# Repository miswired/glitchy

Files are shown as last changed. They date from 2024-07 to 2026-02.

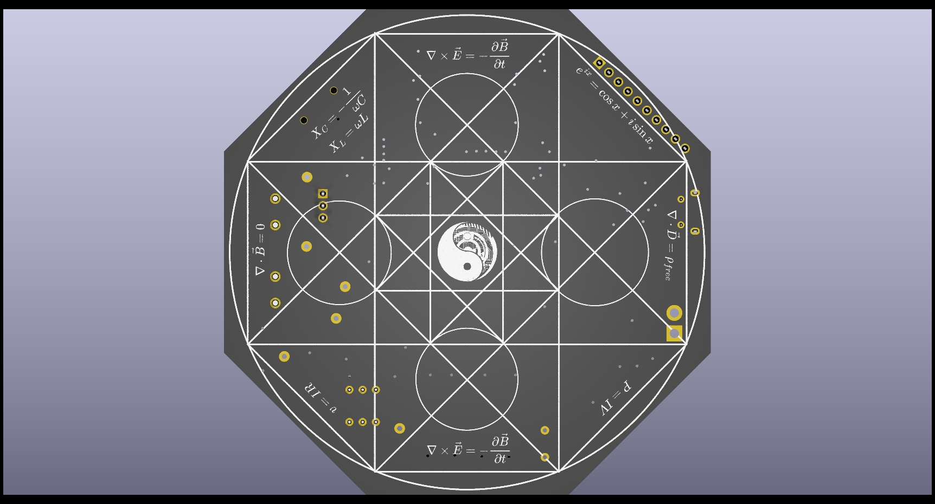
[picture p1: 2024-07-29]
PCB/Docs/Board2.png

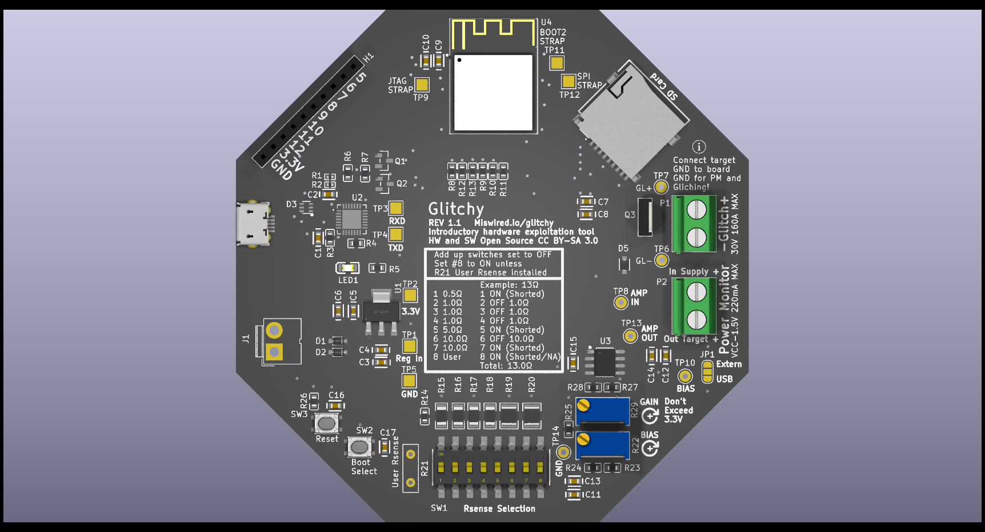
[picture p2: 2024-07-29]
PCB/Docs/Board1.png

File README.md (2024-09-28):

# CircuitBreakerGadget

## Project Overview
Designed as an introduction into hardware hacking, the Glitchy can do power glitching to alter program execution and power analysis for extracting secrets from chips. 
See the [wiki](https://github.com/miswired/glitchy/wiki) for setup instructions and guides to performing the labs with the kit.

## Install
This project is hosted in two repos. The board firmware and PCB is hosted here. Please see the following instructions for setting up the build enviroment and programming. [Arduino-Setup](https://github.com/miswired/glitchy/wiki/Guide-%E2%80%90-Arduino-Setup)   

**The web gui has be substatually upgradded by Philip Kopyscinski!**  
See the following repo for the files you need to put on the SD card.  
https://github.com/pkopysci/miswired-glitchy-vue-app

## Comming Features
* Scripting power analysis attack
* Configure wifi from a config file on sd card isntead of having to reprogram

## Release Notes
### 2.0.0
#### New Features
* Completely new web GUI!!!
* Adjustability of glitching parameters from web interface

### 1.1.0
#### New Features
* None

#### Bug Fixes
* Fixed loading bug for the web interface

#### Backlog

* Add configuration of the glitching settings to the web interface instead of needing to reflash the chip
* Add wifi configuration to a config.ini file on the SD card instead of needing to reflash the chip

## Project Setup
Install Arduino IDE V1. Please see the following wiki for a setup guide. [Arduino-Setup](https://github.com/miswired/glitchy/wiki/Guide-%E2%80%90-Arduino-Setup)  

## Colaborators
**Miswired**  
https://github.com/miswired  
PCB Board and firmware  
  
**Philip J Kopyscinski**  
https://github.com/pkopysci  
Web GUI

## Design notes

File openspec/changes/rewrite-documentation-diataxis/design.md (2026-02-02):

# Design: Documentation Rewrite

## Context

Glitchy is an open-source hardware hacking educational kit targeting security researchers, embedded engineers, and students. Documentation must serve:
- **Beginners**: No prior hardware/security knowledge assumed
- **Experts**: Quick access to technical details without wading through basics
- **Instructors**: Materials for live classroom teaching
- **Contributors**: Clear understanding of project architecture

The Diataxis framework (https://diataxis.fr/) provides a systematic approach by categorizing documentation into four types based on user needs.

## Goals / Non-Goals

### Goals
- Complete restructure of wiki following Diataxis principles
- Fill all documentation gaps (currently 3 major TODOs)
- Create reusable classroom lesson plans
- Design dark-mode compatible SVG diagrams
- Establish consistent formatting standards

### Non-Goals
- Video tutorials (future consideration)
- Translations/internationalization
- Interactive web-based labs
- Changes to firmware or web GUI code

## Decisions

### Decision: Diataxis Four-Quadrant Structure

**Rationale**: Diataxis is proven at Gatsby, Cloudflare, Django. It provides clear separation of concerns:

| Quadrant | User Need | Content Type |
|---|---|---|
| Tutorial | Learning | Lessons with hands-on exercises |
| How-To | Doing | Task-focused guides |
| Reference | Looking up | Technical specifications |
| Explanation | Understanding | Conceptual background |

**Alternatives Considered**:
- Simple linear progression → Doesn't serve expert users well
- Topic-based organization → Mixes learning with reference
- Persona-based (beginner/advanced) → Creates duplication

### Decision: SVG Diagrams with CSS Variables

**Rationale**: SVGs scale perfectly, support theming, and are accessible.

```svg
<svg>
  <style>
    :root { --fg: currentColor; --bg: transparent; }
    @media (prefers-color-scheme: dark) {
      :root { --fg: #E0E0E0; --bg: #121212; }
    }
  </style>
</svg>
```

**Alternatives Considered**:
- PNG with light/dark versions → Doubles maintenance burden
- External Figma embeds → Requires account, breaks offline access
- ASCII art → Insufficient for circuit diagrams

### Decision: Wiki-Embedded Assets

**Rationale**: GitHub wiki repos support assets. Keeping diagrams with docs ensures:
- Single source of truth
- Version control for diagrams
- No external dependencies
- Works offline when cloned

**Directory Structure**:
```
glitchy.wiki/
├── assets/
│   └── diagrams/
│       ├── system-architecture.svg
│       ├── pinout-esp32s3.svg
│       ├── glitch-timing-waveform.svg
│       ├── power-analysis-flow.svg
│       ├── crowbar-circuit.svg
│       └── web-interface-map.svg
```

### Decision: Dual-Format Classroom Materials

**Rationale**: Users want both self-paced study and instructor-led classes.

Each lesson includes:
- **Instructor Guide**: Teaching notes, timing, discussion questions
- **Student Materials**: Exercises, expected outcomes
- **Slide Diagrams**: SVGs optimized for projection

**Lesson Structure**:
```markdown
# Lesson N: Topic

## Overview (Instructor)
- Duration: 45 minutes
- Prerequisites: Lesson N-1
- Materials needed: [list]

## Learning Objectives
Students will be able to:
- [ ] Objective 1
- [ ] Objective 2

## Lesson Content
### Section 1 (10 min)
[Content with instructor notes in blockquotes]

### Hands-On Exercise (20 min)
[Step-by-step with checkpoints]

### Discussion (10 min)
[Questions and wrap-up]

## Self-Study Notes
[Modifications for independent learners]
```

## Risks / Trade-offs

| Risk | Mitigation |
|---|---|
| Large scope causes stalls | Phase implementation: research first, then core docs, then diagrams, then classroom |
| Diagrams become outdated | Store editable sources, document design system |
| Diataxis feels bureaucratic | Keep it pragmatic - serve users, not the framework |
| GitHub wiki limitations | Test rendering early, have fallback plans |
| Inaccurate technical content | Research-first approach with authoritative sources; dual-source verification |
| Unverifiable claims | Every technical claim must cite authoritative source; no unsourced assertions |
| AI hallucination in content | All generated content verified against primary sources before publication |

## Migration Plan

### Phase 0: Research & Verification (NEW - Critical)
1. Compile authoritative sources for all technical topics
2. Research glitching theory from academic papers
3. Research power analysis from foundational DPA/SPA literature
4. Verify circuit design against datasheets and application notes
5. Create Reference-Sources.md documenting all authoritative sources

**Authoritative Sources to Consult:**
- **Hardware Security**: CHES conference papers, Kocher et al. DPA papers, ChipWhisperer research
- **Electronics**: Espressif ESP32-S3 TRM, component datasheets, manufacturer app notes
- **Books**: "Power Analysis Attacks" (Mangard/Oswald/Popp), "The Hardware Hacker" (Huang)
- **Standards**: NIST guidelines on side-channel resistance

### Phase 1: Core Structure (Foundation)
1. Create new directory structure in wiki
2. Migrate existing content to appropriate quadrants
3. Add clear deprecation notices to old locations
4. Create Home.md navigation hub

### Phase 2: Fill Critical Gaps
1. Write PlatformIO setup guide
2. Write power analysis theory explanation
3. Write circuit explanation
4. Create troubleshooting guide

### Phase 3: Visual Assets
1. Design diagram style guide (colors, fonts, spacing)
2. Create system architecture diagram
3. Create pinout diagram
4. Create timing/waveform diagrams
5. Create power analysis flow diagram

### Phase 4: Reference Documentation
1. Document pin assignments
2. Document WebSocket API protocol
3. Document glitch parameters
4. Create Bill of Materials

### Phase 5: Classroom Materials
1. Create instructor overview guide
2. Create Lesson 1: Introduction to Hardware Security
3. Create Lesson 2: Setting Up Your Lab
4. Create Lesson 3: Power Glitching Hands-On
5. Create Lesson 4: Power Analysis Hands-On

### Rollback
- Keep original files until new structure is validated
- Use git branches for major changes
- Maintain redirects from old URLs

## Open Questions

1. **Lesson duration**: Should lessons target 45-min, 60-min, or 90-min class periods?
2. **Prerequisite knowledge**: Should we include embedded systems basics or link externally?
3. **Diagram tool**: Should we standardize on a specific SVG editor (Inkscape, Figma, etc.)?
4. **Assessment**: Should classroom lessons include quizzes or knowledge checks?

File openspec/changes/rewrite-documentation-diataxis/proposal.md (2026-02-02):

# Change: Rewrite Documentation Using Diataxis Framework

## Why

The current wiki documentation has significant gaps that hinder both new users and contributors:
- 3 critical sections marked TODO (PlatformIO setup, Power Analysis Theory, Circuit Explanation)
- Deprecated Arduino IDE guide still prominently displayed
- No visual diagrams or architecture documentation
- Mixed documentation types causing confusion (tutorials vs how-to guides)
- No structured classroom/lesson materials for educational use
- Inconsistent formatting and incomplete troubleshooting

The Diataxis framework provides a proven structure that separates documentation by user need: learning (tutorials), doing (how-to), looking up (reference), and understanding (explanation).

## What Changes

### New Documentation Structure
- **Reorganize all content** into four Diataxis quadrants plus classroom section
- **Create missing documentation**: PlatformIO setup, power analysis theory, circuit explanation, architecture overview, troubleshooting guide
- **Add reference section**: Pinout, Web API protocol, parameters, BOM, schematic reference
- **Add classroom section**: Self-paced modules and instructor-led lesson plans

### Visual Improvements
- **Create SVG diagrams** for: system architecture, pinout, glitch timing, power analysis flow, waveform annotations
- **Design for dark mode**: Use `currentColor`, CSS variables, WCAG-compliant contrast
- **Embed directly in wiki**: Store SVGs in wiki repo for inline rendering

### Deprecation Handling
- **Archive Arduino-Setup.md** with clear migration notice
- **Remove TODO placeholders** by filling in actual content

### Quality Improvements
- **Consistent formatting** across all documents
- **Add estimated times** to tutorials and labs
- **Add prerequisites** to each document
- **Add troubleshooting sections** where appropriate

## Impact

- **Affected specs**: documentation (new capability)
- **Affected repositories**: glitchy.wiki (primary), glitchy/openspec (specs)
- **User impact**: Significantly improved onboarding and learning experience
- **Contributor impact**: Clear structure makes contributions easier
- **Breaking changes**: None - documentation only

## Success Criteria

1. All TODO items resolved with actual content
2. Every document categorized into exactly one Diataxis quadrant
3. Minimum 6 SVG diagrams created with dark mode support
4. Classroom section with at least 4 lesson plans
5. All documentation passes Diataxis validation (no mixed types)
6. New user can go from zero to first successful glitch using only documentation

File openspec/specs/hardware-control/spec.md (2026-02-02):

# Hardware Control Capability

## Purpose
The hardware control module manages low-level hardware interfaces including GPIO pin configuration, SPI bus setup, SD card access, and timer interrupts. It provides the foundation for glitching and power analysis operations.

## Requirements

### Requirement: Pin Configuration
The system SHALL configure GPIO pins according to their designated functions for glitching, power analysis, and communication.

#### Scenario: Glitching pin setup
- **WHEN** the system initializes
- **THEN** POWER_GLITCH_PIN (15) is configured as output for FET control
- **AND** ENTER_KEY_PIN (11) is configured as output for target triggering
- **AND** GLITCH_SUCCESS_PIN (12) is configured as input for success detection

#### Scenario: Analog pin setup
- **WHEN** the system initializes
- **THEN** AMP_IN_PIN (4) is configured for ADC input
- **AND** BIAS_IN_PIN (2) is configured for bias voltage input

#### Scenario: Key input pin setup
- **WHEN** the system initializes
- **THEN** KEY_1_PIN (5), KEY_2_PIN (6), KEY_3_PIN (7) are configured as inputs for differential analysis

### Requirement: SPI Bus Configuration
The system SHALL configure dual SPI buses: FSPI for FET control and HSPI for SD card access.

#### Scenario: FSPI initialization for glitching
- **WHEN** glitch module initializes
- **THEN** FSPI bus is configured with pins 13-16 for high-speed FET control

#### Scenario: HSPI initialization for SD card
- **WHEN** SD card module initializes
- **THEN** HSPI bus is configured with pins 39-41, 47 for SD card communication

### Requirement: SD Card Access
The system SHALL mount and access an SD card for storing the web GUI files and configuration.

#### Scenario: SD card mount on boot
- **WHEN** the system starts
- **THEN** the SD card is mounted and verified accessible

#### Scenario: SD card error handling
- **WHEN** SD card is not present or fails to mount
- **THEN** the system reports the error and continues with limited functionality

### Requirement: Timer Interrupts
The system SHALL use hardware timer interrupts for periodic task scheduling including ADC streaming and status updates.

#### Scenario: Timer initialization
- **WHEN** the system starts
- **THEN** a hardware timer is configured for periodic interrupt callbacks

#### Scenario: Periodic task execution
- **WHEN** timer interrupt fires
- **THEN** scheduled tasks (ADC reads, status updates) are executed

### Requirement: System Initialization Sequence
The system SHALL follow a defined initialization sequence to ensure all hardware is properly configured before operation.

#### Scenario: Boot sequence
- **WHEN** the system powers on
- **THEN** initialization proceeds in order: WiFi, SD card, web server, WebSocket, glitch module, ADC
- **AND** each stage reports success or failure before proceeding

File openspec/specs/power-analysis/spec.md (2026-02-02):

# Power Analysis Capability

## Purpose
The power analysis module provides real-time monitoring of target device power consumption using fast ADC sampling. This enables side-channel attacks where cryptographic secrets can be extracted by analyzing power consumption patterns during cryptographic operations.

## Requirements

### Requirement: Fast ADC Initialization
The system SHALL initialize a fast ADC driver on the AMP_IN_PIN with 12-bit resolution and 11dB attenuation for power measurement.

#### Scenario: ADC setup on boot
- **WHEN** the system starts up
- **THEN** the fast ADC is configured on pin 4 (AMP_IN_PIN) with calibration applied

#### Scenario: ADC calibration
- **WHEN** ADC is initialized
- **THEN** hardware calibration coefficients are applied for accurate voltage readings

### Requirement: Real-Time ADC Streaming
The system SHALL stream ADC samples to the web interface via WebSocket for real-time power consumption visualization.

#### Scenario: Enable streaming mode
- **WHEN** user enables amp bias streaming via web interface
- **THEN** the system continuously samples ADC and sends values over WebSocket

#### Scenario: Streaming rate control
- **WHEN** streaming is active
- **THEN** samples are sent at a configurable rate (default 100ms intervals)

### Requirement: Sample Buffering
The system SHALL maintain sample buffers for differential power analysis across multiple key operations.

#### Scenario: Buffer allocation
- **WHEN** performing differential analysis
- **THEN** three 1000-sample buffers are available for comparing power traces from different key inputs

#### Scenario: Buffer capture on key press
- **WHEN** a key input pin (KEY_1, KEY_2, or KEY_3) is activated
- **THEN** the corresponding buffer captures 1000 ADC samples during the operation

### Requirement: Differential Power Analysis
The system SHALL support differential power analysis by comparing power traces from operations with different input keys.

#### Scenario: Run key difference analysis
- **WHEN** user initiates key difference analysis
- **THEN** the system compares buffered traces to identify power consumption differences correlated with key bits

### Requirement: Voltage Conversion
The system SHALL convert raw ADC values to calibrated voltage readings using DAC-to-voltage conversion constants.

#### Scenario: ADC to voltage conversion
- **WHEN** displaying or transmitting ADC readings
- **THEN** raw values are converted to millivolts using calibration polynomial

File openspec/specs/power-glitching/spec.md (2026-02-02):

# Power Glitching Capability

## Purpose
The power glitching module provides controlled voltage glitch attacks against target devices. It uses an SPI-driven FET to create precise nanosecond-scale power disruptions that can cause instruction skips or data corruption in target microcontrollers.

## Requirements

### Requirement: Glitch Parameter Configuration
The system SHALL allow configuration of glitch timing parameters including shortest delay, longest delay, step size, pause time between attempts, and number of attempts per step.

#### Scenario: Configure glitch parameters via web interface
- **WHEN** user submits new glitch parameters through the web UI
- **THEN** the system updates the internal glitch_param_t structure with the new values

#### Scenario: Default parameter initialization
- **WHEN** the system starts up
- **THEN** glitch parameters are initialized to safe defaults (200ns shortest, 1500ns longest, 10ns step, 3 attempts)

### Requirement: SPI-Driven Glitch Execution
The system SHALL use the FSPI bus to drive the power glitch FET with nanosecond-level timing precision.

#### Scenario: Execute single glitch pulse
- **WHEN** a glitch is triggered
- **THEN** the system sends an SPI transaction to create a precise voltage dip on the target power rail

#### Scenario: Glitch width control
- **WHEN** executing a glitch with a specified width
- **THEN** the FET remains active for the duration specified (within SPI timing constraints)

### Requirement: Automated Timing Sweep
The system SHALL automatically sweep through timing parameters to find vulnerable glitch windows.

#### Scenario: Parameter sweep execution
- **WHEN** user activates glitching via web interface
- **THEN** the system iterates from shortest_delay_ns to longest_delay_ns in step_size increments, executing num_of_attempts glitches at each timing

#### Scenario: Success detection during sweep
- **WHEN** the GLITCH_SUCCESS_PIN goes high during a sweep
- **THEN** the system records the successful timing parameters and reports via WebSocket

### Requirement: Target Trigger Synchronization
The system SHALL synchronize glitch timing with target device operations using the ENTER_KEY_PIN.

#### Scenario: Trigger target before glitch
- **WHEN** executing a glitch sequence
- **THEN** the system pulses ENTER_KEY_PIN to initiate the target operation before applying the glitch

### Requirement: Glitch Status Reporting
The system SHALL report glitch progress and results via WebSocket to the web interface.

#### Scenario: Progress updates during sweep
- **WHEN** a glitch sweep is in progress
- **THEN** the system sends periodic status updates including current timing and attempt count

#### Scenario: Success notification
- **WHEN** a glitch successfully bypasses target security
- **THEN** the system sends a success message with the effective timing parameters

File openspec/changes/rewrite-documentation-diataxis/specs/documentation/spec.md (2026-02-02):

## ADDED Requirements

### Requirement: Diataxis Documentation Structure
The documentation SHALL be organized into four distinct categories following the Diataxis framework: Tutorials (learning-oriented), How-To Guides (task-oriented), Reference (information-oriented), and Explanation (understanding-oriented).

#### Scenario: User seeks to learn a new skill
- **WHEN** a user wants to learn how to use Glitchy for the first time
- **THEN** they find tutorial documentation that guides them through hands-on exercises with clear learning objectives

#### Scenario: User needs to accomplish a specific task
- **WHEN** a user needs to configure WiFi or flash firmware
- **THEN** they find how-to guides focused on completing that specific task without extraneous explanation

#### Scenario: User needs to look up technical details
- **WHEN** a user needs pin assignments, API formats, or parameter specifications
- **THEN** they find reference documentation with authoritative, consistent technical information

#### Scenario: User wants to understand concepts
- **WHEN** a user wants to understand why glitching works or how the circuit is designed
- **THEN** they find explanation documentation that provides context, theory, and background

### Requirement: Classroom Lesson Materials
The documentation SHALL include structured lesson plans suitable for both self-paced learning and instructor-led classroom use.

#### Scenario: Instructor prepares a class
- **WHEN** an instructor wants to teach a hardware security class using Glitchy
- **THEN** they find lesson plans with timing guides, learning objectives, discussion questions, and hands-on exercises

#### Scenario: Student studies independently
- **WHEN** a student works through lessons without an instructor
- **THEN** the lesson materials include self-study notes and self-assessment checkpoints

### Requirement: Dark-Mode Compatible Diagrams
The documentation SHALL include SVG diagrams that render correctly in both light and dark display modes while meeting WCAG accessibility guidelines.

#### Scenario: User views diagram in dark mode
- **WHEN** a user with dark mode enabled views a diagram
- **THEN** the diagram automatically adapts colors for readability with minimum 4.5:1 contrast ratio for text

#### Scenario: Screen reader accesses diagram
- **WHEN** a screen reader encounters an SVG diagram
- **THEN** the diagram provides accessible title and description elements

### Requirement: Complete Reference Documentation
The documentation SHALL include reference materials for all hardware interfaces, software APIs, and configuration parameters.

#### Scenario: Developer looks up pin assignment
- **WHEN** a developer needs to know which GPIO controls the FET
- **THEN** they find a pinout reference with complete pin assignments and electrical specifications

#### Scenario: Developer integrates with web interface
- **WHEN** a developer wants to communicate with Glitchy programmatically
- **THEN** they find WebSocket API documentation with message formats and command reference

### Requirement: Troubleshooting Guide
The documentation SHALL include a troubleshooting guide organized by symptom to help users diagnose and resolve common issues.

#### Scenario: User encounters WiFi connection failure
- **WHEN** a user cannot connect to the Glitchy web interface
- **THEN** they find troubleshooting steps organized under WiFi/connection symptoms

#### Scenario: User's glitch attacks consistently fail
- **WHEN** a user cannot achieve successful glitches after multiple attempts
- **THEN** they find troubleshooting guidance for glitching failures with diagnostic steps

### Requirement: Technical Glossary
The documentation SHALL include a glossary of technical terms covering hardware security, embedded systems, and electronics terminology.

#### Scenario: User encounters unfamiliar term
- **WHEN** a user reads documentation containing technical jargon
- **THEN** they can look up the term in the glossary for a clear definition

### Requirement: Contribution Guidelines
The documentation SHALL include guidelines for contributing to the project including code, documentation, and hardware improvements.

#### Scenario: Developer wants to contribute code
- **WHEN** a developer wants to submit a code improvement
- **THEN** they find clear guidelines on code style, testing requirements, and pull request process

#### Scenario: User wants to report an issue
- **WHEN** a user discovers a bug or has a feature request
- **THEN** they find guidelines on how to report issues effectively

### Requirement: Safety Documentation
The documentation SHALL include consolidated safety guidelines covering electrical safety, soldering practices, ESD precautions, and ethical use.

#### Scenario: New user sets up lab environment
- **WHEN** a new user prepares their workspace for hardware experiments
- **THEN** they find safety guidelines that help prevent equipment damage and personal injury

#### Scenario: User considers real-world application
- **WHEN** a user considers applying techniques to real devices
- **THEN** they find ethical and legal use guidelines with responsible disclosure practices

### Requirement: Citation and Licensing Compliance
The documentation SHALL properly cite and credit all external sources, and SHALL only use content that is compatible with the project's license without introducing licensing conflicts.

#### Scenario: Documentation references external resource
- **WHEN** documentation includes information from an external source (articles, papers, tutorials, images)
- **THEN** the source is properly cited with author, title, URL, and access date where applicable

#### Scenario: Documentation includes external content
- **WHEN** documentation incorporates content created by others (diagrams, code snippets, text)
- **THEN** the content's license is verified as compatible and attribution is provided per license requirements

#### Scenario: User wants to verify sources
- **WHEN** a user wants to learn more or verify information in the documentation
- **THEN** they find clear citations that allow them to locate the original source

#### Scenario: Contributor adds external reference
- **WHEN** a contributor adds content referencing external sources
- **THEN** the contribution guidelines specify citation format and license compatibility requirements

### Requirement: Authoritative Content Verification
The documentation SHALL present only information that has been verified against reputable, authoritative sources. All technical claims, security concepts, and educational content SHALL be researched from expert sources before publication.

#### Scenario: Documenting technical concepts
- **WHEN** documentation explains hardware security concepts (glitching, power analysis, side-channels)
- **THEN** the content is verified against peer-reviewed academic papers, established security research, or recognized industry publications

#### Scenario: Documenting circuit behavior
- **WHEN** documentation describes electrical or circuit behavior
- **THEN** the content is verified against component datasheets, application notes from manufacturers, or established electronics engineering references

#### Scenario: Documenting firmware behavior
- **WHEN** documentation describes ESP32-S3 capabilities or Arduino framework behavior
- **THEN** the content is verified against official Espressif documentation, Arduino reference, or authoritative technical sources

#### Scenario: Making security claims
- **WHEN** documentation makes claims about attack effectiveness, vulnerabilities, or defense mechanisms
- **THEN** the claims are supported by cited research, reproducible experiments, or established security literature

#### Scenario: Content review process
- **WHEN** new technical content is authored
- **THEN** the content undergoes verification against at least two authoritative sources before publication

### Requirement: Printable Quick Reference Materials
The documentation SHALL include printable single-page quick reference cards suitable for lab bench use.

#### Scenario: User needs pinout during lab work
- **WHEN** a user is working at a lab bench and needs to check pin assignments
- **THEN** they have access to a printable single-page pinout reference card

#### Scenario: User needs parameter reference during experimentation
- **WHEN** a user is adjusting glitch parameters and needs to check valid ranges
- **THEN** they have access to a printable parameters cheat sheet

### Requirement: Version Documentation and Compatibility
The documentation SHALL include version history, changelog, and compatibility information to support users across different firmware and hardware revisions.

#### Scenario: User upgrades firmware
- **WHEN** a user wants to upgrade to a new firmware version
- **THEN** they find a changelog documenting what changed and any migration steps required

#### Scenario: User checks version compatibility
- **WHEN** a user needs to verify their firmware and web GUI versions are compatible
- **THEN** they find a compatibility matrix showing which versions work together

#### Scenario: Future hardware revision released
- **WHEN** a new PCB revision is released with hardware differences
- **THEN** the documentation structure supports version-specific information without duplicating entire docs

### Requirement: User Feedback Integration
The documentation SHALL provide a clear mechanism for users to report issues, suggest improvements, and ask questions.

#### Scenario: User finds documentation error
- **WHEN** a user discovers an error or unclear section in the documentation
- **THEN** they find clear instructions to report the issue via GitHub Issues

#### Scenario: User has documentation suggestion
- **WHEN** a user wants to suggest a documentation improvement
- **THEN** they find contribution guidelines explaining how to submit improvements

### Requirement: Basic Accessibility Compliance
The documentation SHALL follow basic accessibility guidelines including proper heading hierarchy, alt text for images, and accessible SVG elements.

#### Scenario: Screen reader navigates documentation
- **WHEN** a user navigates documentation with a screen reader
- **THEN** headings are properly nested (h1 → h2 → h3) enabling hierarchical navigation

#### Scenario: Screen reader encounters image
- **WHEN** a screen reader encounters an image or diagram
- **THEN** meaningful alt text describes the content or purpose of the image

#### Scenario: Screen reader encounters SVG diagram
- **WHEN** a screen reader encounters an SVG diagram
- **THEN** the SVG contains title and desc elements providing accessible descriptions

### Requirement: Further Learning Resources
The documentation SHALL include a curated list of related projects, academic resources, and learning paths with clear non-affiliation disclaimers.

#### Scenario: User wants to learn more
- **WHEN** a user wants to explore related tools and deeper learning resources
- **THEN** they find a Further Learning section with curated recommendations

#### Scenario: User sees related project
- **WHEN** a user views recommended external resources
- **THEN** a clear disclaimer indicates Glitchy is not affiliated with these projects

### Requirement: Downloadable PDF Documentation
The documentation SHALL be available as a downloadable PDF for offline access and printing.

#### Scenario: User needs offline documentation
- **WHEN** a user needs to access documentation without internet connectivity
- **THEN** they can download a complete PDF version of the documentation

#### Scenario: User wants to print documentation
- **WHEN** a user wants to print the full documentation
- **THEN** the PDF is formatted for readable printed output with proper pagination

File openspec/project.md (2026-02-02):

# Project Context

## Purpose
Glitchy (aka "CircuitBreakerGadget") is an open-source hardware hacking educational kit designed to teach hardware exploitation techniques. The project demonstrates two critical hardware attack methodologies:

1. **Power Glitching**: Introducing controlled power glitches to alter program execution flow
2. **Power Analysis**: Extracting secrets by monitoring power consumption patterns (side-channel attacks)

The project aims to be beginner-friendly while demonstrating real-world security vulnerabilities in embedded systems. It serves security researchers, embedded systems engineers, hardware enthusiasts, and students learning hardware exploitation.

## Tech Stack

### Hardware Platform
- **MCU**: ESP32-S3-DevKitC-1 (primary controller)
- **Power Control**: High-speed FET (Field Effect Transistor) for crowbar glitching
- **Analog Monitoring**: ADC circuits for power analysis
- **Communication**: WiFi connectivity
- **Target Device**: Arduino Uno R3 (for educational labs)

### Firmware Development
- **Build System**: PlatformIO
- **Framework**: Arduino
- **Language**: C/C++
- **IDE**: VS Code with PlatformIO extension (recommended)

### Core Libraries
- AsyncTCP - TCP/IP stack for ESP32
- ESPAsyncWebServer - Async web server for HTTP/WebSocket
- ArduinoJson (v7.3.1+) - JSON communication
- Custom Fast ADC driver (ESP32-S3-FastAnalogRead)

### Frontend
- Vue.js-based web application (separate repo: https://github.com/pkopysci/miswired-glitchy-vue-app)
- Served from SD card via async web server
- Real-time WebSocket communication

### PCB Design
- KiCad EDA for schematics and layouts

## Project Conventions

### Code Style
- C/C++ with Arduino conventions
- Function names: snake_case (e.g., `init_glitch()`, `setup_fast_adc()`)
- Constants/Macros: UPPER_SNAKE_CASE (e.g., `POWER_GLITCH_PIN`, `AMP_IN_PIN`)
- Structs: snake_case with `_t` suffix (e.g., `glitch_param_t`)
- Global state variables: prefixed with `g_` (e.g., `g_glitching_activate`)

### Architecture Patterns
- **Client-Controller Architecture**: ESP32-S3 board controls glitching, target device receives attacks
- **Event-Driven**: Timer interrupts for periodic tasks, async web server for non-blocking I/O
- **Modular Design**: Separate modules for glitching, analog, and web server functionality
- **State Management**: Global getter/setter pairs for cross-module state (e.g., `get_glitching_activate()`, `set_glitching_activate()`)

### File Organization
```
Code/Glitchy/
├── src/              # Implementation files (.cpp)
│   ├── main.cpp      # Entry point, WiFi, SD card init
│   ├── glitching.cpp # Glitch attack logic
│   ├── webserver.cpp # Web interface and WebSocket
│   └── analog_helpers.cpp # Power analysis ADC functions
├── include/          # Header files (.h)
│   ├── pins.h        # Pin definitions
│   ├── global.h      # Shared definitions
│   ├── glitching.h   # Glitch module interface
│   ├── web_server.h  # Web server interface
│   └── analog.h      # Fast ADC driver
└── platformio.ini    # Build configuration
```

### Testing Strategy
- Manual testing with physical hardware setup (Glitchy board + Arduino Uno target)
- Web UI testing via browser
- No automated unit tests currently (hardware-dependent codebase)

### Git Workflow
- Main branch contains stable releases
- Feature branches for development
- Version tags for releases (e.g., v2.0.0)

## Domain Context

### Hardware Security Concepts
- **Power Glitching**: Momentarily dropping power to a chip causes instruction skips or data corruption, potentially bypassing security checks
- **Crowbar Circuit**: Uses FET to short power rails momentarily, creating voltage dips
- **Timing Window**: Glitches must occur at precise moments (nanosecond precision) to be effective
- **Power Analysis**: Measuring power consumption can reveal information about data being processed (side-channel attack)

### Key Parameters
- **Glitch Width**: Duration of power dip (typically 200ns - 1500ns)
- **Glitch Timing**: When to trigger relative to target operation
- **Sweep Parameters**: Iteratively test timing ranges to find vulnerable windows

### Pin Mapping (ESP32-S3)
| Pin | Function | Description |
|-----|---|---|
| 15  | POWER_GLITCH_PIN | FET control for glitching |
| 11  | ENTER_KEY_PIN | Trigger target device |
| 12  | GLITCH_SUCCESS_PIN | Monitor attack success |
| 4 | AMP_IN_PIN | Amplified power measurement |
| 2 | BIAS_IN_PIN | Bias voltage input |
| 5,6,7 | KEY_1/2/3_PIN | Key inputs for differential analysis |

## Important Constraints

### Hardware Constraints
- Timing precision limited by SPI bus speed (~18ns minimum glitch width)
- ADC resolution: 12-bit with 11dB attenuation
- SD card required for web GUI files
- WiFi connectivity required for web interface

### Safety Constraints
- Educational use only - not for malicious purposes
- Glitching can damage target devices if misconfigured
- Power analysis requires proper signal conditioning

### Compatibility
- Requires ESP32-S3 specifically (not ESP32 or ESP32-S2)
- Target examples designed for Arduino Uno R3
- Web GUI requires modern browser with WebSocket support

## External Dependencies

### Hardware
- ESP32-S3-DevKitC-1 development board
- Custom Glitchy PCB (KiCad files in PCB/ directory)
- Arduino Uno R3 (for target labs)
- SD card for web GUI storage

### Software/Services
- PlatformIO for firmware builds
- Web GUI: https://github.com/pkopysci/miswired-glitchy-vue-app
- No cloud services required - fully offline capable

### Documentation
- Wiki: https://github.com/miswired/glitchy/wiki
- Theory, quick start guides, and lab tutorials available

## Collaborators
- **Miswired** (https://github.com/miswired): PCB design and firmware
- **Philip J Kopyscinski** (https://github.com/pkopysci): Web GUI implementation

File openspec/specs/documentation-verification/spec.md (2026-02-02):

# Capability: Documentation Verification

## Overview

The documentation verification system ensures all technical claims in Glitchy documentation are validated against authoritative sources. This prevents inaccurate information from reaching users and maintains documentation quality standards.

## Requirements

### Requirement: Verification File Per Document

Documentation verification SHALL create one verification file per source document being verified.

**Rationale**: Modular verification files allow parallel work, clear tracking, and isolated git history per document.

#### Scenario: Creating verification file for tutorial

- **GIVEN** a documentation file `Tutorial-Getting-Started.md` exists in the wiki
- **WHEN** verification is needed
- **THEN** create `verifications/VERIFICATION-Tutorial-Getting-Started.md`
- **AND** the verification filename SHALL match the source document filename exactly with `VERIFICATION-` prefix

#### Scenario: Verification file location

- **GIVEN** wiki documentation exists at repository root
- **WHEN** creating verification files
- **THEN** all verification files SHALL be stored in `verifications/` directory at repository root
- **AND** verification files SHALL NOT be nested in subdirectories

### Requirement: Verification File Format

Verification files SHALL include status summary, claims listing, authoritative sources, verification status, and notes for each claim.

**Rationale**: Standardized format ensures consistency and makes verification results easy to review.

#### Scenario: Recording verified claim

- **GIVEN** a technical claim "Pin 15 controls power glitch FET"
- **WHEN** verified against source code at `pins.h:15`
- **THEN** verification entry SHALL include:
  - Claim text
  - Source reference with file path and line number
  - Confidence level (HIGH/MEDIUM/LOW/UNKNOWN)
  - Status icon (✓ Verified | ❌ Incorrect | ⚠️ Needs Testing | ? Unknown)
  - Notes with additional context

#### Scenario: Recording unverified claim

- **GIVEN** a claim "Default WiFi SSID is 'Glitchy'"
- **WHEN** no source found in code or documentation
- **THEN** mark with status "⚠️ Needs Testing"
- **AND** set confidence "LOW" or "UNKNOWN"
- **AND** note what testing is required

#### Scenario: Status summary header

- **GIVEN** a verification file with multiple claims
- **WHEN** updating verification status
- **THEN** file SHALL include header with:
  - Overall status (In Progress / Complete / Needs Review)
  - Count of verified claims (e.g., "5/12 verified")
  - Last updated date
  - Link to source document being verified

### Requirement: Confidence Levels

All verified claims SHALL be marked with a confidence level indicating the strength of evidence.

**Rationale**: Distinguishes between rock-solid evidence (official docs) and assumptions that need testing.

#### Scenario: HIGH confidence assignment

- **GIVEN** a claim verified against official documentation, source code, or hardware testing
- **WHEN** recording verification status
- **THEN** set confidence to "HIGH"
- **EXAMPLES**:
  - ESP32-S3 Technical Reference Manual
  - Verified in project source code
  - Tested on physical Glitchy hardware

#### Scenario: MEDIUM confidence assignment

- **GIVEN** a claim inferred from verified sources or found in secondary sources
- **WHEN** recording verification status
- **THEN** set confidence to "MEDIUM"
- **EXAMPLES**:
  - Logically derived from HIGH confidence claims
  - Academic papers or technical books
  - Component datasheets for non-primary components

#### Scenario: LOW confidence assignment

- **GIVEN** a claim based on assumptions, anecdotal evidence, or incomplete sources
- **WHEN** recording verification status
- **THEN** set confidence to "LOW"
- **EXAMPLES**:
  - Assumed from project naming
  - Blog posts or forum discussions
  - Untested configurations

#### Scenario: UNKNOWN confidence assignment

- **GIVEN** a claim with no source found
- **WHEN** recording verification status
- **THEN** set confidence to "UNKNOWN"
- **AND** note that investigation or expert review is required

### Requirement: Authoritative Sources

Technical claims SHALL be verified against authoritative sources only.

**Rationale**: Ensures accuracy by requiring primary sources rather than secondary interpretations or assumptions.

#### Scenario: PRIMARY source - Official documentation

- **GIVEN** a claim about ESP32-S3 hardware capabilities
- **WHEN** verifying the claim
- **THEN** acceptable sources include:
  - Espressif ESP32-S3 Technical Reference Manual
  - ESP32-S3 Datasheet
  - Official Espressif documentation

#### Scenario: PRIMARY source - Project source code

- **GIVEN** a claim about Glitchy firmware behavior
- **WHEN** verifying the claim
- **THEN** verify against actual source code
- **AND** record file path and line numbers
- **EXAMPLE**: `Code/Glitchy/include/pins.h:15`

#### Scenario: PRIMARY source - Hardware schematics

- **GIVEN** a claim about circuit design or pin connections
- **WHEN** verifying the claim
- **THEN** verify against KiCad schematic files
- **AND** record schematic reference and revision

#### Scenario: SECONDARY source - Academic papers

- **GIVEN** a claim about glitching or power analysis theory
- **WHEN** official documentation unavailable
- **THEN** acceptable secondary sources include:
  - Peer-reviewed academic papers (CHES, IEEE S&P, USENIX Security)
  - Technical books (e.g., "Power Analysis Attacks" by Mangard et al.)
- **AND** record full citation

#### Scenario: INVALID source - Unverifiable

- **GIVEN** a claim found only in blog posts, forums, or undocumented code comments
- **WHEN** no authoritative source available
- **THEN** mark as "UNVERIFIED"
- **AND** note "Requires expert review" or "Needs hardware testing"

#### Scenario: Hardware testing as source

- **GIVEN** a claim about runtime behavior (WiFi SSID, default IP, timing values)
- **WHEN** not documented in code or configuration
- **THEN** verification requires testing on physical Glitchy hardware
- **AND** mark as "⚠️ Needs Testing" until confirmed
- **AND** record test procedure and results when tested

### Requirement: Verification Index

The verification directory SHALL maintain a README.md index showing status of all verifications.

**Rationale**: Provides quick overview of verification progress and entry point for the verification system.

#### Scenario: Checking overall progress

- **GIVEN** multiple verification files exist in `verifications/` directory
- **WHEN** user wants to check verification status
- **THEN** `verifications/README.md` SHALL display table with:
  - Document name (linked to verification file)
  - Status (Not Started / In Progress / Complete / Needs Review)
  - Count of verified claims
  - Count of issues found
  - Last updated date

#### Scenario: Index includes implementation guide

- **GIVEN** a contributor wants to create a verification file
- **WHEN** they read `verifications/README.md`
- **THEN** README SHALL include:
  - Overview of verification system
  - How to create new verification files
  - Link to TEMPLATE.md
  - Verification checklist
  - Reference to OpenSpec spec (this document)

#### Scenario: Index links to OpenSpec tracking

- **GIVEN** verification work is tracked in OpenSpec
- **WHEN** reading verification README
- **THEN** include link to OpenSpec tasks.md for high-level tracking
- **EXAMPLE**: "See `../glitchy/openspec/changes/rewrite-documentation-diataxis/tasks.md` for task tracking"

### Requirement: Verification Template

A template file SHALL be provided to ensure consistent verification file format.

**Rationale**: Reduces friction for creating new verification files and ensures format consistency.

#### Scenario: Creating new verification from template

- **GIVEN** a new document needs verification
- **WHEN** contributor creates verification file
- **THEN** copy `verifications/TEMPLATE.md`
- **AND** rename to `VERIFICATION-{document-name}.md`
- **AND** fill in document-specific content following template structure

#### Scenario: Template includes examples

- **GIVEN** contributor is new to verification process
- **WHEN** using the template
- **THEN** template SHALL include:
  - Example claims with all confidence levels
  - Example status icons
  - Example source citations
  - Comments explaining each section

### Requirement: OpenSpec Integration

Documentation verification SHALL integrate with OpenSpec task tracking at a high level.

**Rationale**: OpenSpec tracks WHAT documents need verification, verification files track HOW claims were verified.

#### Scenario: Task completion tracking

- **GIVEN** a document verification is complete
- **WHEN** all claims verified and issues resolved
- **THEN** mark corresponding task in OpenSpec tasks.md as complete
- **AND** update verification file status to "Complete"
- **AND** update verification index

#### Scenario: High-level task structure

- **GIVEN** OpenSpec change for documentation verification
- **WHEN** defining tasks in tasks.md
- **THEN** create one task per document being verified
- **EXAMPLE**: "- [ ] 0.2 Verify Tutorial-Getting-Started.md"
- **AND** reference verification files for details

### Requirement: Agent Instructions

AI agents working on documentation SHALL be instructed to follow verification process.

**Rationale**: Ensures future documentation changes maintain quality standards.

#### Scenario: Agent modifies documentation

- **GIVEN** an AI agent creates or modifies documentation
- **WHEN** documentation contains technical claims
- **THEN** agent SHALL create or update verification file
- **AND** verify claims against authoritative sources
- **AND** mark claims appropriately (verified, needs testing, etc.)

#### Scenario: Agent instructions location

- **GIVEN** agent instructions exist in project
- **WHEN** documenting verification process
- **THEN** add verification workflow to:
  - `AGENTS.md` or `CLAUDE.md` in glitchy repository
  - Reference OpenSpec spec for detailed requirements
  - Link to `verifications/README.md` for implementation guide

## Non-Requirements

### Not Required: Automated Verification

The system does NOT require automated testing or CI/CD integration. Verification is a manual process performed by humans and AI agents during documentation work.

### Not Required: Version Tracking

The system does NOT require tracking verification across documentation versions. Git history provides version control. Re-verification is performed when documentation changes.

### Not Required: External Tool Integration

The system does NOT require integration with external documentation tools, linters, or validators beyond standard markdown and git.

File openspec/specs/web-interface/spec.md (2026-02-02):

# Web Interface Capability

## Purpose
The web interface module provides a browser-based control panel for the Glitchy device. It uses an async HTTP server with WebSocket support for real-time communication. The frontend Vue.js application is served from an SD card.

## Requirements

### Requirement: Async HTTP Server
The system SHALL host an async HTTP web server on port 80 for serving the web GUI and handling API requests.

#### Scenario: Server initialization
- **WHEN** the system starts and WiFi is connected
- **THEN** an async HTTP server starts on port 80

#### Scenario: Static file serving
- **WHEN** a browser requests files (HTML, CSS, JS)
- **THEN** the server serves files from the SD card root directory

### Requirement: WebSocket Communication
The system SHALL provide a WebSocket endpoint at /ws for real-time bidirectional communication with the web GUI.

#### Scenario: WebSocket connection
- **WHEN** the web GUI connects to /ws
- **THEN** a persistent WebSocket connection is established

#### Scenario: Receive commands via WebSocket
- **WHEN** the web GUI sends a JSON command
- **THEN** the server parses and executes the command (e.g., start glitching, update parameters)

#### Scenario: Send updates via WebSocket
- **WHEN** glitch status changes or ADC data is available
- **THEN** the server pushes JSON updates to connected clients

### Requirement: WiFi Connectivity
The system SHALL support both Access Point (AP) mode and client (station) mode for WiFi connectivity.

#### Scenario: Default AP mode
- **WHEN** the system starts without stored WiFi credentials
- **THEN** it creates an access point for direct connection

#### Scenario: Client mode connection
- **WHEN** valid WiFi credentials are configured
- **THEN** the system connects to the specified network as a client

### Requirement: JSON API Protocol
The system SHALL use JSON format for all WebSocket message exchanges with defined message types for commands and responses.

#### Scenario: Glitch parameter update message
- **WHEN** sending glitch parameters to the GUI
- **THEN** the message contains all timing parameters in a structured JSON object

#### Scenario: ADC streaming message
- **WHEN** streaming power analysis data
- **THEN** ADC values are sent as JSON arrays with timestamp information

### Requirement: State Synchronization
The system SHALL maintain synchronized state between firmware and web GUI using getter/setter functions and WebSocket updates.

#### Scenario: GUI requests current state
- **WHEN** the web GUI connects or requests state
- **THEN** the server sends current glitch parameters and system status

#### Scenario: State change notification
- **WHEN** firmware state changes (e.g., glitching starts/stops)
- **THEN** connected clients receive immediate notification

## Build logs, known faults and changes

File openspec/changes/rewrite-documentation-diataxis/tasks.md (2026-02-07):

# Tasks: Documentation Rewrite

## Phase 0a: Verification of Live Documentation (NEW - Added 2026-02-01)

**Purpose**: Verify technical accuracy of documentation already published on master branch before creating new content.

- [x] 0a.1 Create verification system infrastructure (COMPLETE - 2026-02-01)
  - [x] Create OpenSpec spec: `openspec/specs/documentation-verification/spec.md`
  - [x] Create `verifications/` directory in wiki
  - [x] Create `verifications/README.md` implementation guide
  - [x] Create `verifications/TEMPLATE.md`
  - [x] Update agent instructions (AGENTS.md or CLAUDE.md)
- [x] 0a.2 Verify Tutorial-Getting-Started.md (COMPLETE - 2026-02-01)
  - [x] Extract and verify all technical claims (35/35 verified)
  - [x] Create `verifications/VERIFICATION-Tutorial-Getting-Started.md`
  - [x] Update verification index
- [x] 0a.3 Verify Tutorial-First-Glitch.md (COMPLETE - 2026-02-01)
  - [x] Extract and verify all technical claims (40/40 verified)
  - [x] Create `verifications/VERIFICATION-Tutorial-First-Glitch.md`
  - [x] Update verification index
- [x] 0a.4 Verify HowTo-Setup-PlatformIO.md (COMPLETE - 2026-02-02)
  - [x] Extract and verify all technical claims (32/32 verified, 3 issues fixed)
  - [x] Create `verifications/VERIFICATION-HowTo-Setup-PlatformIO.md`
  - [x] Update verification index
- [x] 0a.5 Verify HowTo-Flash-Firmware.md (COMPLETE - 2026-02-02)
  - [x] Extract and verify all technical claims (25/25 verified, 3 issues fixed)
  - [x] Create `verifications/VERIFICATION-HowTo-Flash-Firmware.md`
  - [x] Update verification index
- [x] 0a.6 Verify HowTo-Configure-WiFi.md (COMPLETE - 2026-02-02)
  - [x] Extract and verify all technical claims (22/22 verified, 3 issues fixed)
  - [x] Create `verifications/VERIFICATION-HowTo-Configure-WiFi.md`
  - [x] Update verification index
- [x] 0a.7 Verify HowTo-Update-WebGUI.md (COMPLETE - 2026-02-02)
  - [x] Extract and verify all technical claims (28/28 verified, 4 issues fixed)
  - [x] Create `verifications/VERIFICATION-HowTo-Update-WebGUI.md`
  - [x] Update verification index
- [x] 0a.8 Verify HowTo-Setup-KiCad.md (COMPLETE - 2026-02-02)
  - [x] Extract and verify all technical claims (26/26 verified, 2 issues fixed)
  - [x] Create `verifications/VERIFICATION-HowTo-Setup-KiCad.md`
  - [x] Update verification index
- [x] 0a.9 Verify HowTo-Troubleshoot.md (COMPLETE - 2026-02-02)
  - [x] Extract and verify all technical claims (45/45 verified, 5 issues fixed)
  - [x] Create `verifications/VERIFICATION-HowTo-Troubleshoot.md`
  - [x] Update verification index
- [x] 0a.10 Fix all identified issues (COMPLETE - 2026-02-02)
  - [x] Fix 2 major path issues (WebGUI, KiCad)
  - [x] Fix CH340 driver references (3 docs)
  - [x] Fix deprecated PlatformIO commands (2 docs)
  - [x] Fix WiFi startup time estimates (2 docs)
  - [x] Fix firmware version references (2 docs)
  - [x] Fix minor issues (AP password, SD card clarification, etc.)

## Phase 0b: Code Quality Improvements (Identified During Verification)

**Purpose**: Address minor code documentation and clarity issues identified during documentation verification.

- [ ] 0b.1 Add FAT32 requirement comment to SD card initialization
  - Location: Code/Glitchy/src/main.cpp near SD.begin() (line ~56)
  - Add comment: "// SD card must be formatted as FAT32"
  - Rationale: Makes filesystem requirement explicit for developers
  - Severity: Minor (improves code clarity)
  - Source: Tutorial-Getting-Started verification
- [ ] 0b.2 Explicitly set Access Point IP address
  - Location: Code/Glitchy/src/main.cpp in initWiFi() function
  - Add: WiFi.softAPConfig(IPAddress(192,168,4,1), IPAddress(192,168,4,1), IPAddress(255,255,255,0));
  - Rationale: Makes IP configuration explicit instead of relying on ESP32 library default
  - Severity: Minor (improves code clarity)
  - Source: Tutorial-Getting-Started verification
- [ ] 0b.3 Fix Target_glitch file path reference case sensitivity
  - Location: Tutorial-First-Glitch.md, Part 3, step 3
  - Change: "Code/Target Examples/Target_Glitch/" to "Code/Target Examples/Target_glitch/"
  - Rationale: Actual directory uses lowercase 'g'; case-sensitive on Linux/Mac
  - Severity: Minor (prevents confusion on case-sensitive systems)
  - Source: Tutorial-First-Glitch verification

## Phase 0: Research & Source Verification (For New Documentation)

- [ ] 0.1 Compile authoritative source list for hardware security topics
  - Academic papers on fault injection and power analysis
  - Established security conferences (CHES, USENIX Security, IEEE S&P)
  - Books: "The Hardware Hacker" (Huang), "Power Analysis Attacks" (Mangard et al.)
  - ChipWhisperer documentation and research
- [ ] 0.2 Compile authoritative source list for electronics/embedded topics
  - ESP32-S3 Technical Reference Manual (Espressif official)
  - Arduino framework documentation
  - Component datasheets (FET, op-amps, ADC)
  - Application notes from manufacturers
- [ ] 0.3 Research and document glitching theory from academic sources
  - Voltage fault injection papers
  - Timing analysis research
  - Document source references for each claim
- [ ] 0.4 Research and document power analysis theory from academic sources
  - DPA/SPA foundational papers (Kocher et al.)
  - Statistical analysis methods
  - Document source references for each claim
- [ ] 0.5 Research circuit design principles from authoritative sources
  - Crowbar circuit design references
  - Analog front-end design application notes
  - Op-amp configuration references
- [ ] 0.6 Create source reference document (Reference-Sources.md)
  - Categorized list of all authoritative sources used
  - Brief description of each source's authority
  - Links to papers, datasheets, documentation

## Phase 1: Foundation & Structure

- [ ] 1.1 Create wiki directory structure (assets/diagrams/, tutorials/, how-to/, reference/, explanation/, classes/)
- [x] 1.2 Create new Home.md with Diataxis-organized navigation (LIVE on master)
- [ ] 1.3 Create documentation style guide (formatting conventions, heading levels, code blocks)
  - Accessibility guidelines (proper heading hierarchy, alt text requirements)
  - Consistent heading structure for screen reader navigation
  - Image/diagram alt text requirements
- [ ] 1.4 Archive Arduino-Setup.md with deprecation notice and migration path

## Phase 2: Tutorials (Learning-Oriented)

- [x] 2.1 Rewrite Tutorial-Getting-Started.md (first 30 minutes with Glitchy) (LIVE on master)
  - Prerequisites section
  - Estimated time
  - What you'll learn
  - Step-by-step with checkpoints
- [x] 2.2 Rewrite Tutorial-First-Glitch.md (migrate from current Guide) (LIVE on master)
  - Clear learning objectives
  - Expected outcomes at each step
  - Troubleshooting inline
- [ ] 2.3 Rewrite Tutorial-First-Analysis.md (migrate from current Guide)
  - Move IMPORTANT notes to top
  - Add safety section
  - Clear success criteria
- [ ] 2.4 Create Tutorial-Custom-Target.md (NEW)
  - Writing vulnerable code for practice
  - Setting up custom hardware targets

## Phase 3: How-To Guides (Task-Oriented)

- [x] 3.1 Create HowTo-Setup-PlatformIO.md (CRITICAL - currently missing) (LIVE on master)
  - Installation steps
  - Project configuration
  - Building and uploading
  - Common issues
- [x] 3.2 Rewrite HowTo-Flash-Firmware.md (LIVE on master)
  - Separate SD card vs firmware procedures
  - Version verification steps
  - Rollback procedure
- [x] 3.3 Rewrite HowTo-Configure-WiFi.md (LIVE on master)
  - When to use AP vs Client mode
  - Step-by-step for each mode
  - Connection verification
- [x] 3.4 Rewrite HowTo-Setup-KiCad.md (LIVE on master)
  - Opening Glitchy project files
  - Making modifications
  - Exporting for manufacturing
- [x] 3.5 Create HowTo-Troubleshoot.md (NEW) (LIVE on master)
  - Categorized by symptom
  - WiFi issues
  - Glitching failures
  - Power analysis problems
  - Web interface issues
- [x] 3.6 Create HowTo-Update-WebGUI.md (NEW) (LIVE on master)
  - Downloading releases
  - SD card preparation
  - Verification

## Phase 4: Reference Documentation (Lookup-Oriented)

- [ ] 4.1 Create Reference-Pinout.md (NEW)
  - Complete ESP32-S3 pin assignments
  - Pin function table
  - Electrical specifications
- [ ] 4.2 Create Reference-Web-API.md (NEW)
  - WebSocket protocol documentation
  - JSON message formats
  - Command reference
- [ ] 4.3 Create Reference-Parameters.md (NEW)
  - All glitch_param_t fields
  - Valid ranges and defaults
  - Effect of each parameter
- [ ] 4.4 Create Reference-BOM.md (NEW)
  - Complete Bill of Materials
  - Part numbers and suppliers
  - Substitution notes
- [ ] 4.5 Create Reference-Schematic.md (NEW)
  - Circuit block descriptions
  - Key component explanations
  - Links to datasheets
- [ ] 4.6 Create Reference-Glossary.md (NEW)
  - Technical terms: glitch, crowbar, side-channel, DPA, SPA, FET, etc.
  - Hardware terms: ADC, GPIO, SPI, UART
  - Security terms: bypass, fault injection, timing attack
- [ ] 4.7 Create Reference-FAQ.md (NEW)
  - Common questions organized by category
  - Quick answers with links to detailed docs
  - Troubleshooting quick reference
- [ ] 4.8 Create Reference-Changelog.md (NEW)
  - Version history (firmware + web GUI)
  - What changed in each release
  - Breaking changes highlighted
  - Migration notes between versions
- [ ] 4.9 Create Reference-Version-Compatibility.md (NEW)
  - Firmware ↔ Web GUI compatibility matrix
  - Hardware revision notes (for future revisions)
  - Deprecation notices

## Phase 5: Explanation Documentation (Understanding-Oriented)

- [ ] 5.1 Rewrite Explain-Glitching-Theory.md
  - Add conceptual diagrams
  - Expand physics explanation
  - Historical context
  - Link to academic papers
- [ ] 5.2 Create Explain-Power-Analysis.md (CRITICAL - currently TODO)
  - DPA/SPA theory
  - Statistical analysis basics
  - Why it works
- [ ] 5.3 Create Explain-Circuit-Design.md (CRITICAL - currently TODO)
  - FET crowbar circuit explanation
  - Analog front-end design
  - Design trade-offs
- [ ] 5.4 Create Explain-Architecture.md (NEW)
  - System block diagram explanation
  - Firmware module overview
  - Web interface architecture
  - Communication protocols
- [ ] 5.5 Create Explain-Security-Context.md (NEW)
  - Real-world applications
  - Defense strategies
  - Ethical considerations
  - Legal notes
- [ ] 5.6 Create Reference-Further-Learning.md (NEW)
  - Related projects (ChipWhisperer, etc.) with non-affiliation disclaimer
  - Academic resources and papers
  - Similar tools and platforms
  - Recommended learning paths
  - Books and courses
  - Clear disclaimer: "These are recommended resources; Glitchy is not affiliated with these projects"

## Phase 6: SVG Diagrams

- [ ] 6.1 Create diagram style guide
  - Color palette (dark mode compatible)
  - Font specifications
  - Line weights and spacing
  - Accessibility requirements
- [ ] 6.2 Create system-architecture.svg
  - ESP32-S3, FET, Target, Web Browser blocks
  - Connection flows
  - Signal labels
- [ ] 6.3 Create pinout-esp32s3.svg
  - Physical pin layout
  - Function color coding
  - Legend
- [ ] 6.4 Create glitch-timing-waveform.svg
  - Annotated voltage waveform
  - Timing labels
  - Normal vs glitched comparison
- [ ] 6.5 Create power-analysis-flow.svg
  - Data flow from target to analysis
  - ADC sampling visualization
  - Processing stages
- [ ] 6.6 Create crowbar-circuit.svg
  - Schematic-style diagram
  - Component labels
  - Signal flow
- [ ] 6.7 Create web-interface-map.svg
  - UI navigation diagram
  - Feature locations

## Phase 7: Classroom Materials

- [ ] 7.1 Create Class-Overview.md
  - Course structure
  - Prerequisites for instructors
  - Materials checklist
  - Timing recommendations
- [ ] 7.2 Create Lesson-01-Introduction.md
  - Hardware security landscape
  - Attack categories
  - Why glitching matters
  - Brief prerequisite overview with external links
  - (45 min)
- [ ] 7.3 Create Lesson-02-Hardware-Setup.md
  - Lab environment setup
  - Tool familiarization
  - Safety briefing
  - Embedded basics overview with external links
  - (45 min)
- [ ] 7.4 Create Lesson-03-Glitching-Lab.md
  - Hands-on glitching exercise
  - Parameter exploration
  - Success analysis
  - (45 min)
- [ ] 7.5 Create Lesson-04-Analysis-Lab.md
  - Power monitoring setup
  - Trace capture
  - Differential analysis
  - (45 min)
- [ ] 7.6 Create slides/ directory with presentation SVGs

## Phase 7a: Printable Quick Reference Materials

- [ ] 7.6a Create QuickRef-Pinout.pdf (NEW)
  - Single-page printable pinout diagram
  - Pin functions and color coding
  - Designed for lab bench posting
- [ ] 7.6b Create QuickRef-Parameters.pdf (NEW)
  - Glitch parameter quick reference
  - Valid ranges, defaults, effects
  - Single-page format
- [ ] 7.6c Create QuickRef-Commands.pdf (NEW)
  - Web interface quick reference
  - Common operations cheat sheet
  - WebSocket command summary
- [ ] 7.6d Create QuickRef-Troubleshooting.pdf (NEW)
  - Common problems and quick fixes
  - Decision tree format
  - Single-page printable

## Phase 7b: Community & Safety Documentation

- [ ] 7.7 Create Contributing.md (NEW)
  - How to contribute (code, docs, hardware)
  - Code style guidelines
  - Pull request process
  - Issue reporting guidelines (use GitHub Issues for doc feedback)
  - Citation format requirements (author, title, URL, date)
  - License compatibility checklist (CC-BY, MIT, Apache 2.0, public domain)
  - Attribution requirements for external content
  - Documentation update process and versioning guidelines
- [ ] 7.8 Create Safety-Guide.md (NEW)
  - Electrical safety guidelines
  - Soldering safety
  - ESD precautions
  - Legal and ethical use guidelines
  - Responsible disclosure practices

## Phase 7c: PDF Export

- [ ] 7.9 Set up PDF generation pipeline
  - Tool selection (Pandoc, markdown-pdf, or similar)
  - Template design matching wiki style
  - Dark/light mode variants
- [ ] 7.10 Generate complete documentation PDF
  - Combined single PDF with all sections
  - Table of contents with page numbers
  - Printable format optimization
- [ ] 7.11 Create PDF download instructions in wiki
  - Link to latest PDF release
  - Version information

## Phase 8: Quality Assurance

- [ ] 8.1 Review all documents for Diataxis compliance (no mixed types)
- [ ] 8.2 Test all internal links
- [ ] 8.3 Verify SVG rendering in GitHub wiki (light and dark mode)
- [ ] 8.3a Accessibility review
  - Verify proper heading hierarchy in all docs
  - Verify alt text on all images and diagrams
  - Test SVG accessibility (title/desc elements)
- [ ] 8.4 Walk through complete new user journey
- [ ] 8.5 Walk through contributor journey
- [ ] 8.6 Proofread for typos and consistency
- [ ] 8.7 Verify all external citations are complete and properly formatted
- [ ] 8.8 Audit all external content for license compatibility
- [ ] 8.9 Technical accuracy review against authoritative sources
  - Verify all glitching claims against research papers
  - Verify all power analysis claims against DPA literature
  - Verify all circuit descriptions against datasheets
  - Verify all ESP32-S3 claims against Espressif documentation
- [ ] 8.10 Expert review checkpoint (if available)
  - Have hardware security practitioner review technical content
  - Have embedded systems expert review firmware content
- [ ] 8.11 Update openspec/specs with final documentation capability

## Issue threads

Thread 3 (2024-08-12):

PCB Wifi Range Enhancment

miswired, 2024-08-12:
The ground plane in PCB version 1.1  was overlooked and poured underneath the ESP32 antenna. This is likely degrading the range though it seems to work just fine. Pull back the ground plane in the next rev of the board.

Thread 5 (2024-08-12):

Feature - add glitching parameters to web interface

miswired, 2024-08-12:
Right not the min, max, step time, and time to wait between each glitch is hard coded and the board has to be reprogrammed. Move those parameters to the web guide so it's tunable.

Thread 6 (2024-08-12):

Feature Wifi config

miswired, 2024-08-12:
Move wifi setup to a config file on the SD card so the board doesn't need to be reprogrammed to set it.

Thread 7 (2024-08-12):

Improve SD card speed

miswired, 2024-08-12:
The SD card is currently using SPI to communicate, but the full mmc controller is wired up. Transition the library to use the controller for double the SD card speed.

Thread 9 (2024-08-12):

Feature Scripting behavior in browser

miswired, 2024-08-12:
Some kind of language or buttons to create a sequence like block programming. This way the user can pick which IO gets triggered and when and when reads or glitches happen.

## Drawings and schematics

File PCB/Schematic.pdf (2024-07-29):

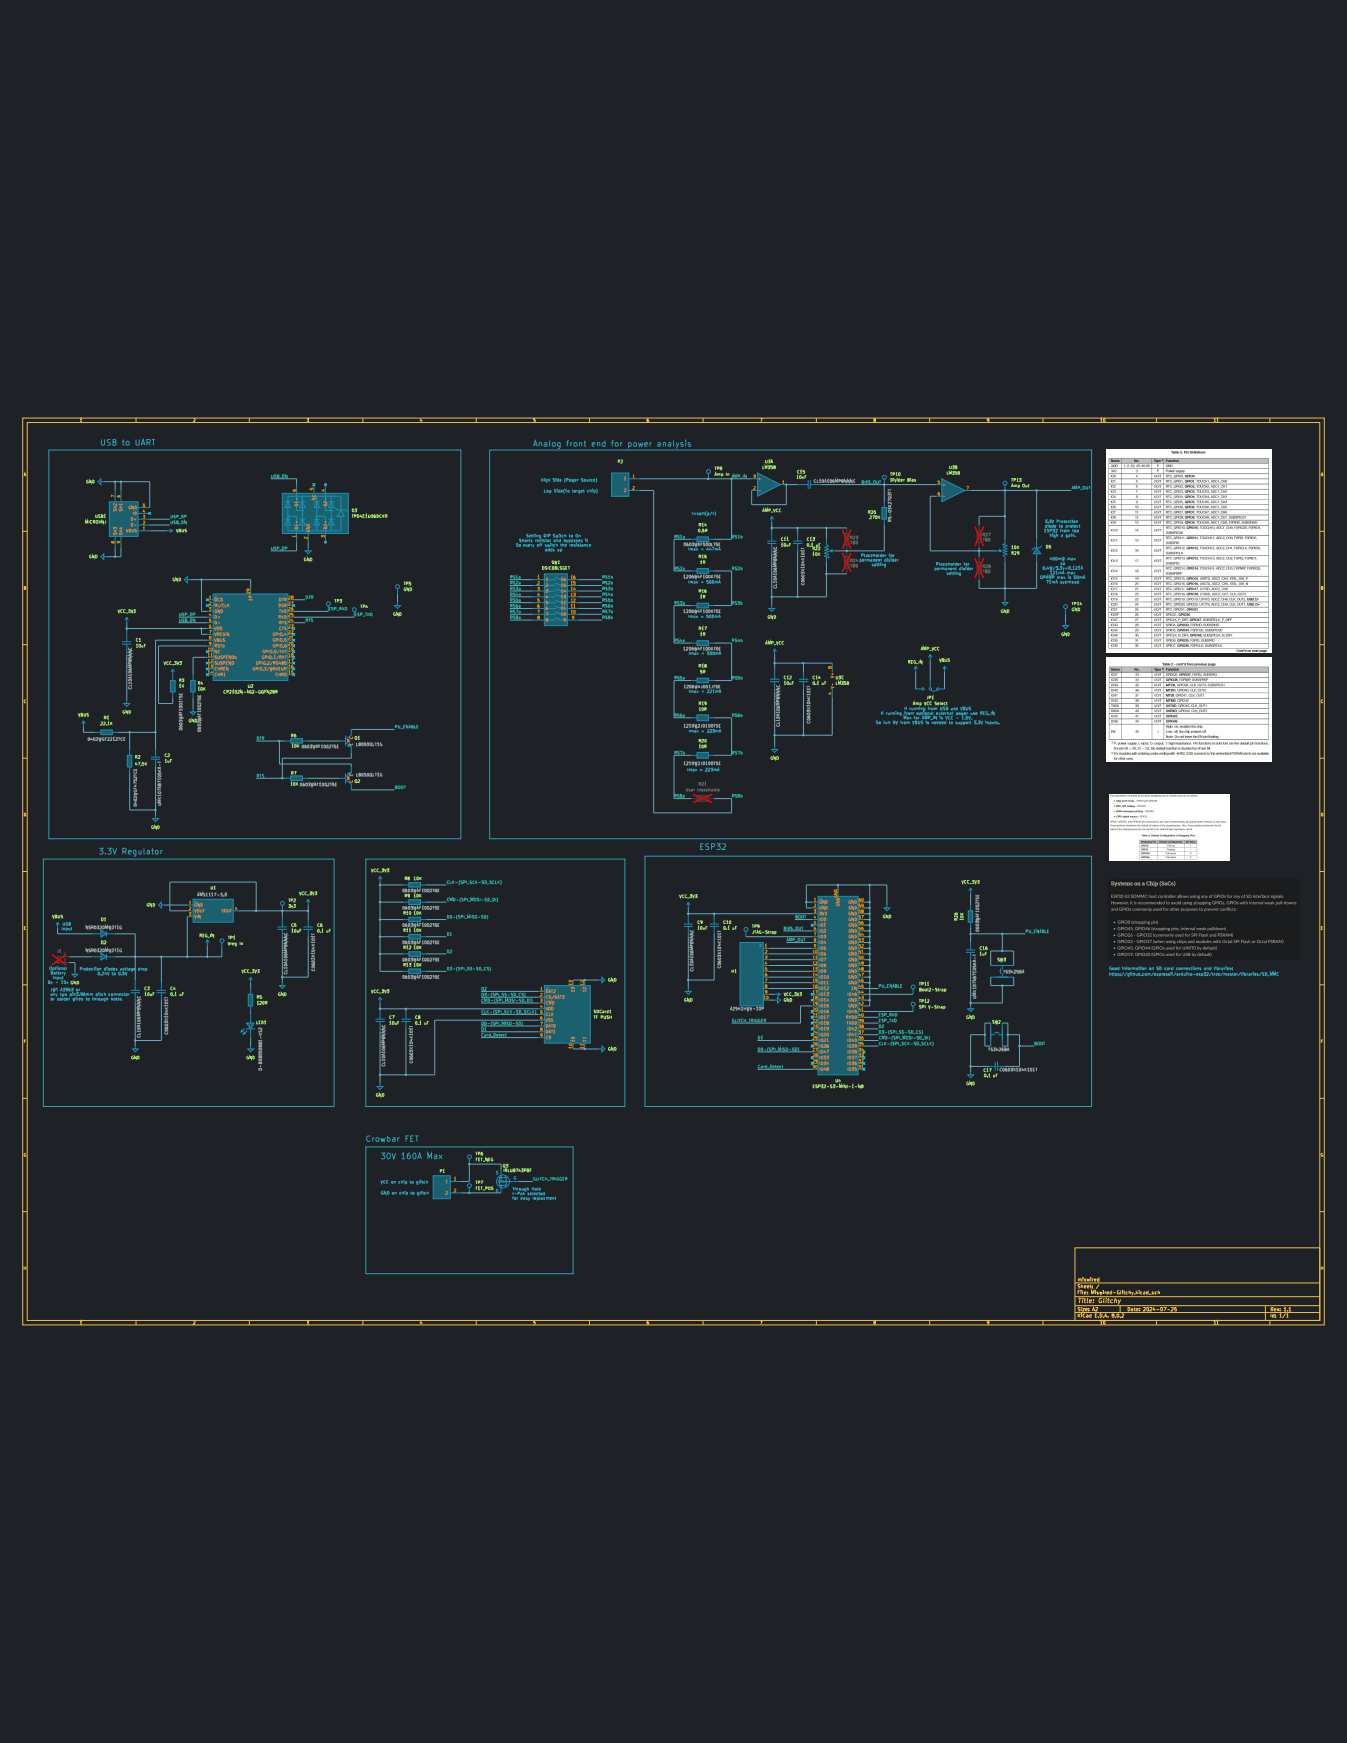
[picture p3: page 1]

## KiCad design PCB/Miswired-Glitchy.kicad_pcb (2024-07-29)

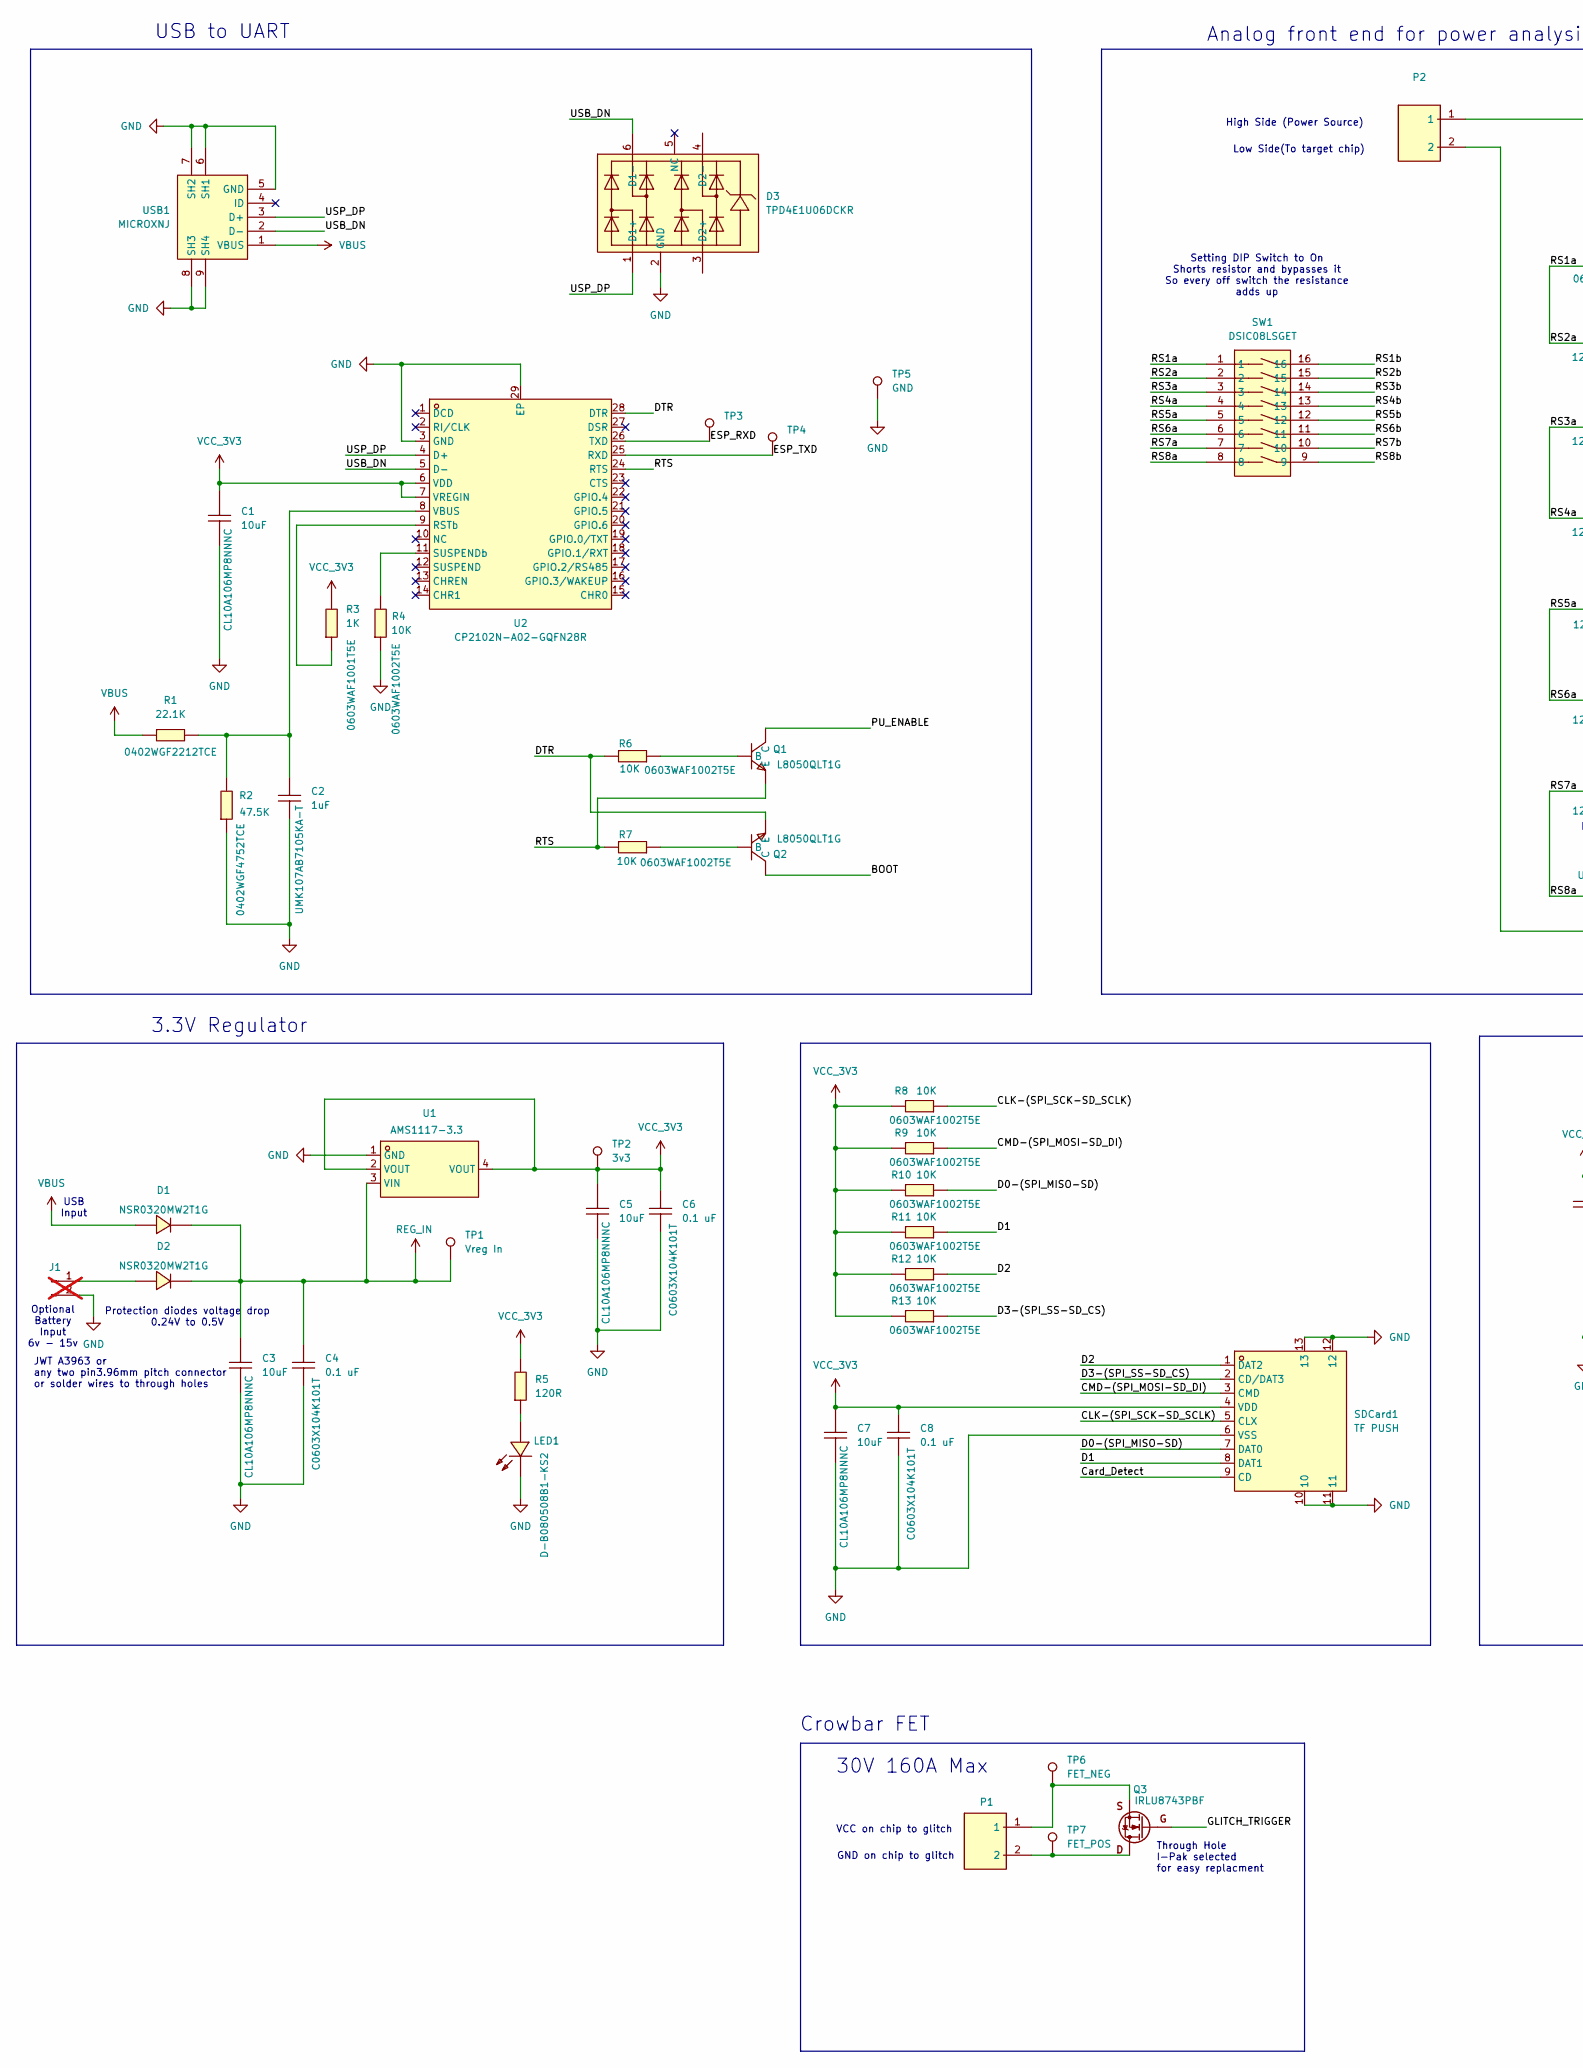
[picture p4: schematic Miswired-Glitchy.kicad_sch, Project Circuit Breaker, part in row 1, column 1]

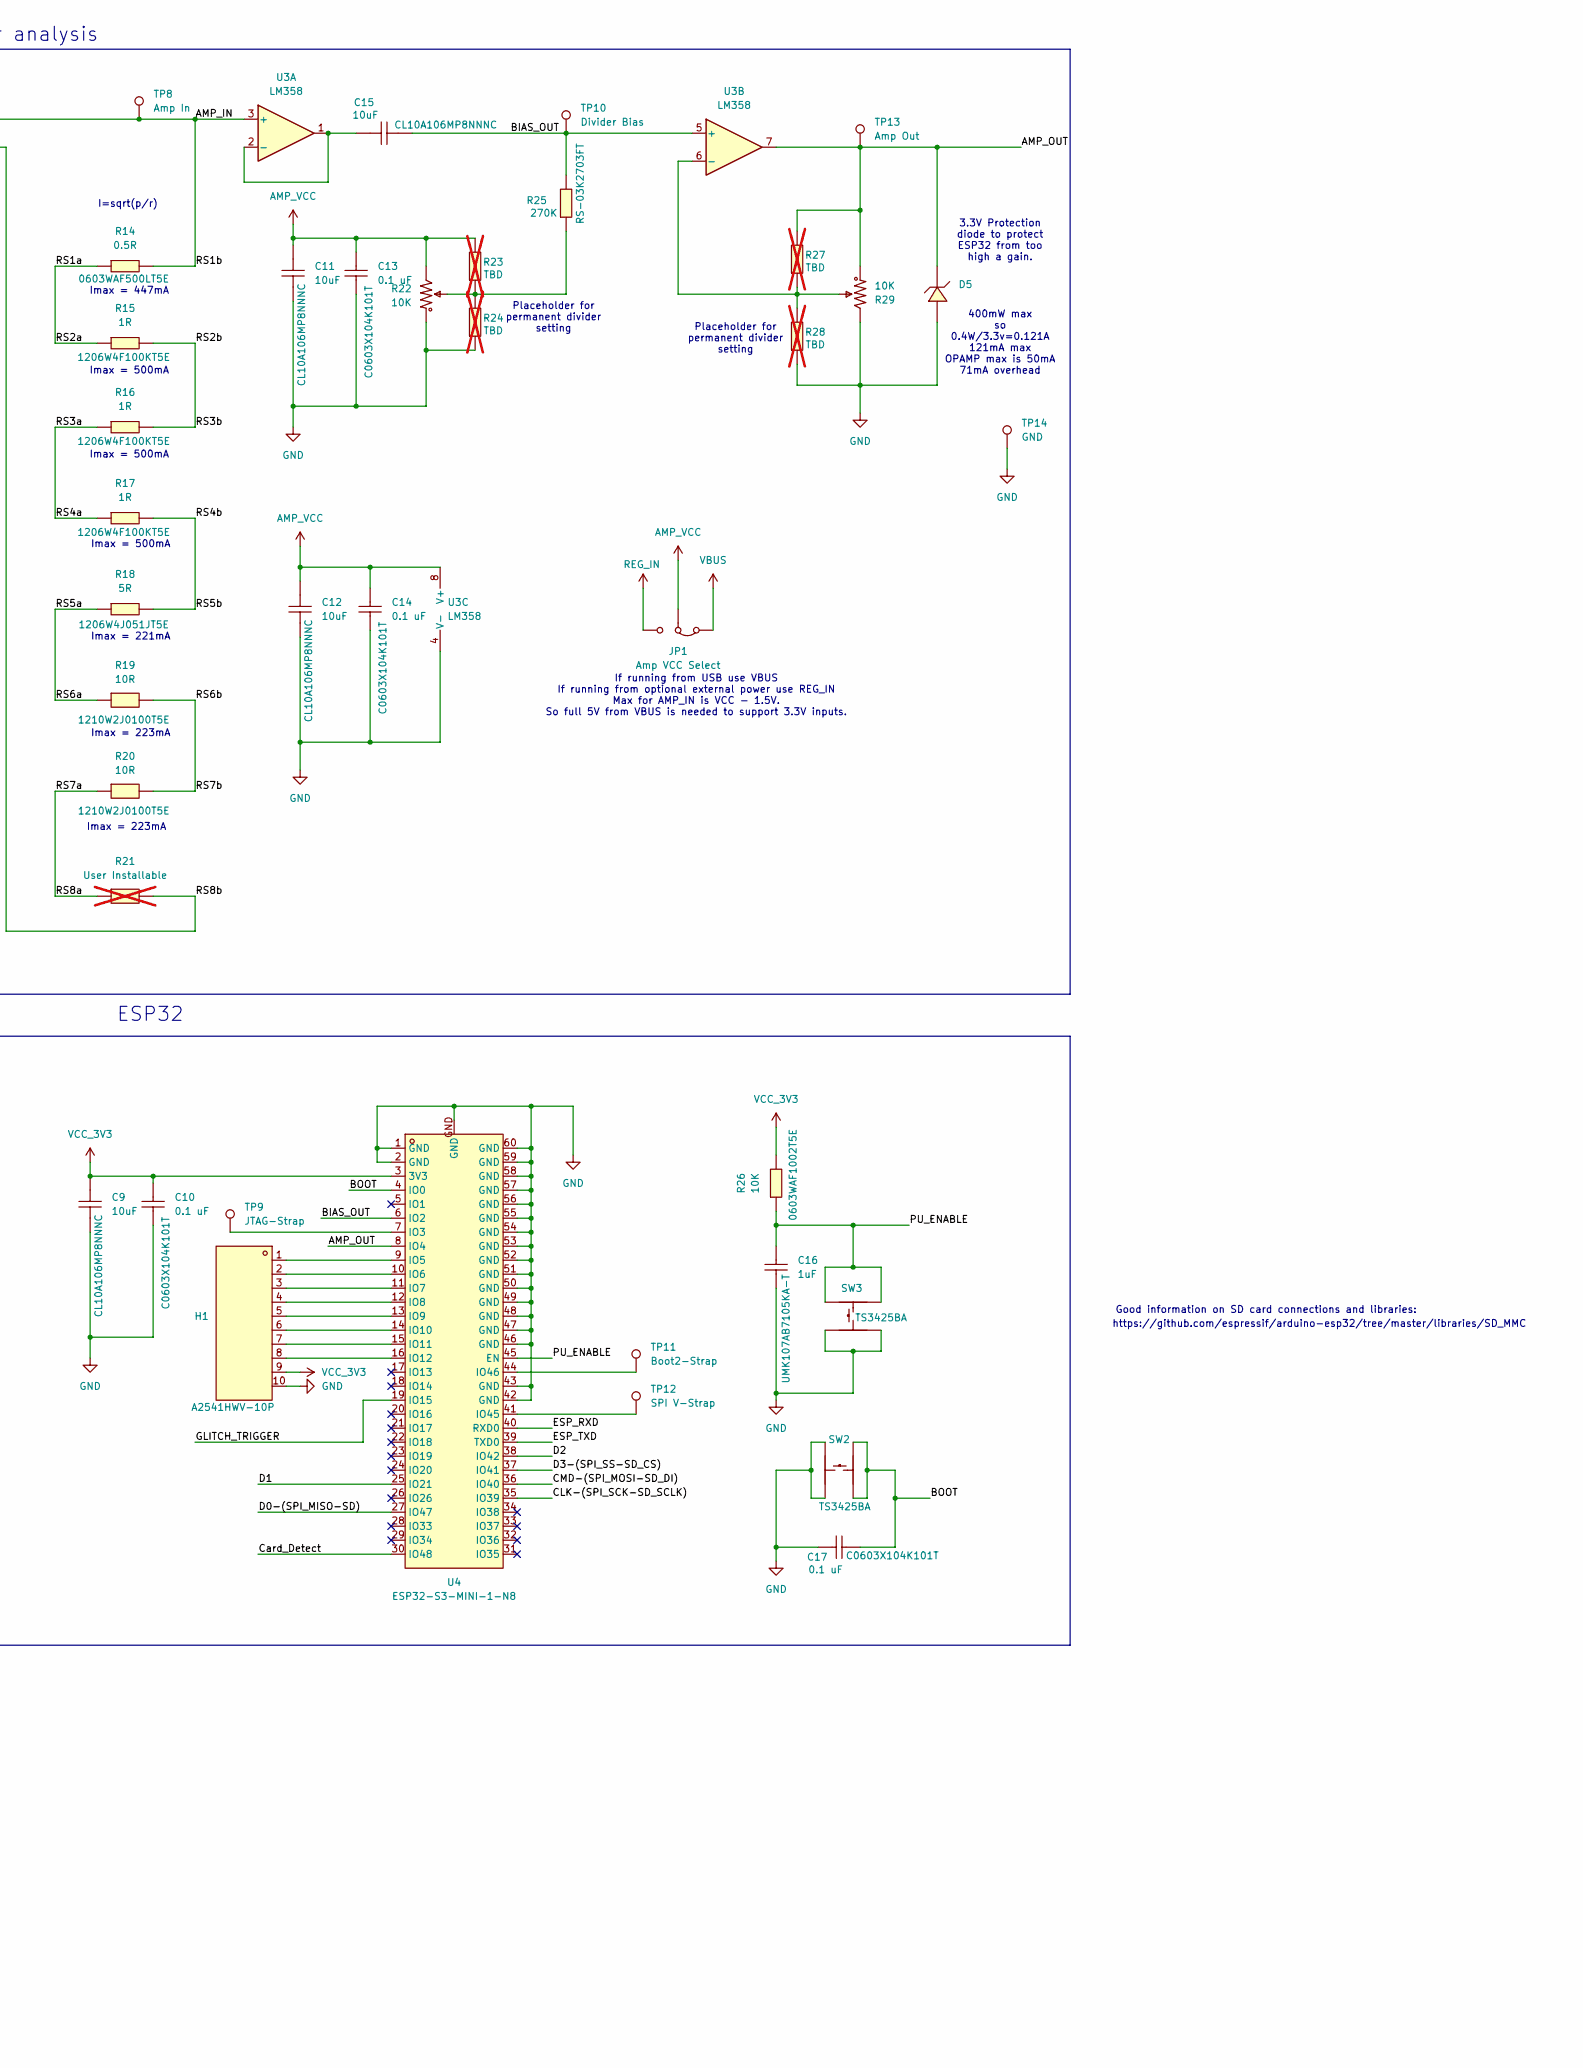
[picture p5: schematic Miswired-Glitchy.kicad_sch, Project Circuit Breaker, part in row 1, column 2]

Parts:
C1, C3, C5, C7, C9, C11, C12, C15: 10uF; C0603; MPN CL10A106MP8NNNC; LCSC Part C85713
C2, C16: 1uF; C0603; MPN UMK107AB7105KA-T; LCSC Part C105174
C4, C6, C8, C10, C13, C14, C17: 0.1 uF; C0603; MPN C0603X104K101T; LCSC Part C105907
D1, D2: SOD-323_L1.8-W1.3-LS2.5-RD; MPN NSR0320MW2T1G; LCSC Part C48192
D3: TPD4E1U06DCKR; SC-70-6_L2.2-W1.3-P0.65-LS2.1-BL; LCSC Part C194628
D5: PDZ3.3B,115; SOD-323_L1.7-W1.3-LS2.5-RD; MPN PDZ3.3B,115; LCSC Part C426855
H1: HDR-TH_10P-P2.54-V-F-1; MPN A2541HWV-10P; LCSC Part C225507
J1: Battery Placeholder; JWT_A3963_1x02_P3.96mm_Vertical; not fitted
JP1: Amp VCC Select; SolderJumper-3_P1.3mm_Bridged12_RoundedPad1.0x1.5mm_NumberL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
LED1: Blue; LED0805-RD; MPN D-B080508B1-KS2; LCSC Part C108412
P1, P2: CONN-TH_WJ126V-5.0-2P; MPN WJ126V-5.0-2P; LCSC Part C8404
Q1, Q2: SOT-23-3_L2.9-W1.3-P1.90-LS2.4-BR; MPN L8050QLT1G; LCSC Part C49581
Q3: IRLU8743PBF; TO-251-3_Vertical; MPN IRLU8743PBF
R1: 22.1K; R0402; MPN 0402WGF2212TCE; LCSC Part C43473
R2: 47.5K; R0402; MPN 0402WGF4752TCE; LCSC Part C25896
R3: 1K; R0603; MPN 0603WAF1001T5E; LCSC Part C21190
R4, R6, R7, R8, R9, R10, R11, R12, R13, R26: 10K; R0603; MPN 0603WAF1002T5E; LCSC Part C25804
R5: 120R; R0603; MPN 0603WAF1200T5E; LCSC Part C22787
R14: 0.5R; R0603; MPN 0603WAF500LT5E; LCSC Part C45312
R15, R16, R17: 1R; R1206; MPN 1206W4F100KT5E; LCSC Part C17928
R18: 5R; R1206; MPN 1206W4J051JT5E; LCSC Part C37912
R19, R20: 10R; R1210; MPN 1210W2J0100T5E; LCSC Part C473562
R21: User Installable; R_Box_L8.4mm_W2.5mm_P5.08mm; not fitted
R22, R29: 10K; RES-ADJ-TH_3P-L10.0-W10.0-P2.50-L; MPN 3296W-1-103; LCSC Part C118954
R23, R24, R27, R28: TBD; R0603; not fitted
R25: 270K; R0603; MPN RS-03K2703FT; LCSC Part C310276
SDCard1: TF PUSH; TF-SMD_TF-PUSH; LCSC Part C393941
SW1: DSIC08LSGET; SW-SMD_DSIC08LSGET; LCSC Part C54953
SW2, SW3: SW-SMD_4P-L4.2-W3.2-P2.15-LS4.6-1; MPN TS3425BA; LCSC Part C2681476
TP1: Vreg In; TestPoint_Pad_2.0x2.0mm
TP2: 3v3; TestPoint_Pad_2.0x2.0mm
TP3, TP4: TestPoint_Pad_2.0x2.0mm
TP5: GND; TestPoint_Pad_2.0x2.0mm
TP6: FET_NEG; TestPoint_THTPad_D2.0mm_Drill1.0mm
TP7: FET_POS; TestPoint_THTPad_D2.0mm_Drill1.0mm
TP8: Amp In; TestPoint_THTPad_D2.0mm_Drill1.0mm
TP9: JTAG-Strap; TestPoint_Pad_2.0x2.0mm
TP10: Divider Bias; TestPoint_THTPad_D2.0mm_Drill1.0mm
TP11: Boot2-Strap; TestPoint_Pad_2.0x2.0mm
TP12: SPI V-Strap; TestPoint_Pad_2.0x2.0mm
TP13: Amp Out; TestPoint_THTPad_D2.0mm_Drill1.0mm
TP14: GND; TestPoint_THTPad_D2.0mm_Drill1.0mm
U1: SOT-223-3_L6.5-W3.4-P2.30-LS7.0-BR; MPN AMS1117-3.3; LCSC Part C6186
U2: CP2102N-A02-GQFN28R; QFN-28_L5.0-W5.0-P0.50-TL-EP3.3; LCSC Part C964632
U3: LM358; SOP-8_L4.9-W3.9-P1.27-LS6.0-BL; MPN LM358DT; LCSC Part C9418
U4: ESP32-S3-MINI-1-N8; BULETM-SMD_ESP32-S3-MINI-1-N8; LCSC Part C2913206
USB1: MICROXNJ; MICRO-USB-SMD_MICROXNJ; LCSC Part C404969

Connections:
/AMP_IN: P2.1, R14.2, SW1.16, TP8.1, U3.3 (+)
/AMP_OUT: D5.1 (K), R27.2, R29.1, TP13.1, U3.7, U4.8 (IO4)
/BIAS_OUT: C15.2, R25.2, TP10.1, U3.5 (+), U4.6 (IO2)
/BOOT: C17.2, Q2.3 (C), SW2.1, SW2.2, U4.4 (IO0)
/CLK-(SPI_SCK-SD_SCLK): R8.1, SDCard1.5 (CLX), U4.35 (IO39)
/CMD-(SPI_MOSI-SD_DI): R9.1, SDCard1.3 (CMD), U4.36 (IO40)
/Card_Detect: SDCard1.9 (CD), U4.30 (IO48)
/D0-(SPI_MISO-SD): R10.1, SDCard1.7 (DAT0), U4.27 (IO47)
/D1: R11.1, SDCard1.8 (DAT1), U4.25 (IO21)
/D2: R12.1, SDCard1.1 (DAT2), U4.38 (IO42)
/D3-(SPI_SS-SD_CS): R13.1, SDCard1.2 (CD/DAT3), U4.37 (IO41)
/DTR: Q2.2 (E), R6.2, U2.28 (DTR)
/ESP_RXD: TP3.1, U2.26 (TXD), U4.40 (RXD0)
/ESP_TXD: TP4.1, U2.25 (RXD), U4.39 (TXD0)
/GLITCH_TRIGGER: Q3.1 (G), U4.19 (IO15)
/PU_ENABLE: C16.2, Q1.3 (C), R26.1, SW3.1, SW3.2, U4.45 (EN)
/RS1a: R14.1, R15.1, SW1.1, SW1.2
/RS2b: R15.2, R16.2, SW1.14, SW1.15
/RS3a: R16.1, R17.1, SW1.3, SW1.4
/RS4b: R17.2, R18.2, SW1.12, SW1.13
/RS5a: R18.1, R19.1, SW1.5, SW1.6
/RS6b: R19.2, R20.2, SW1.10, SW1.11
/RS7a: R20.1, R21.1, SW1.7, SW1.8
/RS8b: P2.2, R21.2, SW1.9
/RTS: Q1.2 (E), R7.2, U2.24 (RTS)
/USB_DN: D3.6 (D1-), U2.5 (D-), USB1.2 (D-)
/USP_DP: D3.1 (D1+), U2.4 (D+), USB1.3 (D+)
AMP_VCC: C11.1, C12.1, C13.2, C14.2, JP1.2 (C), R22.3, R23.2, U3.8 (V+)
GND: C1.2, C2.1, C3.2, C4.1, C5.2, C6.1, C7.2, C8.1, C9.2, C10.1, C11.2, C12.2, C13.1, C14.1, C16.1, C17.1, D3.2 (GND), D5.2 (A), H1.10, J1.2, LED1.1 (K), R2.1, R4.1, R22.1, R24.1, R28.1, R29.3, SDCard1.6 (VSS), SDCard1.10, SDCard1.11, SDCard1.12, SDCard1.13, SW2.3, SW2.4, SW3.3, SW3.4, TP5.1, TP14.1, U1.1 (GND), U2.3 (GND), U2.29 (EP), U3.4 (V-), U4.1 (GND), U4.2 (GND), U4.42 (GND), U4.43 (GND), U4.46 (GND), U4.47 (GND), U4.48 (GND), U4.49 (GND), U4.50 (GND), U4.51 (GND), U4.52 (GND), U4.53 (GND), U4.54 (GND), U4.55 (GND), U4.56 (GND), U4.57 (GND), U4.58 (GND), U4.59 (GND), U4.60 (GND), U4.GND, USB1.5 (GND), USB1.6 (SH1), USB1.7 (SH2), USB1.8 (SH3), USB1.9 (SH4)
unnamed: D2.2 (A), J1.1
unnamed: LED1.2 (A), R5.1
unnamed: Q1.1 (B), R6.1
unnamed: Q2.1 (B), R7.1
unnamed: P1.2, Q3.2 (D), TP7.1
unnamed: P1.1, Q3.3 (S), TP6.1
unnamed: R22.2, R23.1, R24.2, R25.1
unnamed: R3.1, U2.9 (RSTb)
unnamed: R4.2, U2.11 (SUSPENDb)
unnamed: C2.2, R1.2, R2.2, U2.8 (VBUS)
unnamed: C15.1, U3.1, U3.2 (-)
unnamed: R27.1, R28.2, R29.2, U3.6 (-)
unnamed: TP9.1, U4.7 (IO3)
unnamed: H1.1, U4.9 (IO5)
unnamed: H1.2, U4.10 (IO6)
unnamed: H1.3, U4.11 (IO7)
unnamed: H1.4, U4.12 (IO8)
unnamed: H1.5, U4.13 (IO9)
unnamed: H1.6, U4.14 (IO10)
unnamed: H1.7, U4.15 (IO11)
unnamed: H1.8, U4.16 (IO12)
unnamed: TP12.1, U4.41 (IO45)
unnamed: TP11.1, U4.44 (IO46)
REG_IN: C3.1, C4.2, D1.1 (C), D2.1 (C), JP1.3 (B), TP1.1, U1.3 (VIN)
VBUS: D1.2 (A), JP1.1 (A), R1.1, USB1.1 (VBUS)
VCC_3V3: C1.1, C5.1, C6.2, C7.1, C8.2, C9.1, C10.2, H1.9, R3.2, R5.2, R8.2, R9.2, R10.2, R11.2, R12.2, R13.2, R26.2, SDCard1.4 (VDD), TP2.1, U1.2 (VOUT), U1.4 (VOUT), U2.6 (VDD), U2.7 (VREGIN), U4.3 (3V3)

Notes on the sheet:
Good information on SD card connections and libraries:
400mW max so 0.4W/3.3v=0.121A 121mA max OPAMP max is 50mA 71mA overhead
Placeholder for permanent divider setting
High Side (Power Source)
If running from USB use VBUS If running from optional external power use REG_IN Max for AMP_IN is VCC - 1.5V. So full 5V from VBUS is needed to support 3.3V inputs.
Imax = 500mA
https://github.com/espressif/arduino-esp32/tree/master/libraries/SD_MMC
Crowbar FET
Imax = 223mA
Low Side(To target chip)
3.3V Regulator
GND on chip to glitch
Optional Battery Input 6v - 15v
ESP32
Imax = 221mA
Setting DIP Switch to On Shorts resistor and bypasses it So every off switch the resistance adds up
I=sqrt(p/r)
Through Hole I-Pak selected for easy replacment
VCC on chip to glitch
3.3V Protection diode to protect ESP32 from too high a gain.
30V 160A Max
USB to UART
JWT A3963 or any two pin3.96mm pitch connector or solder wires to through holes
Imax = 447mA
Protection diodes voltage drop 0.24V to 0.5V
Analog front end for power analysis
USB Input

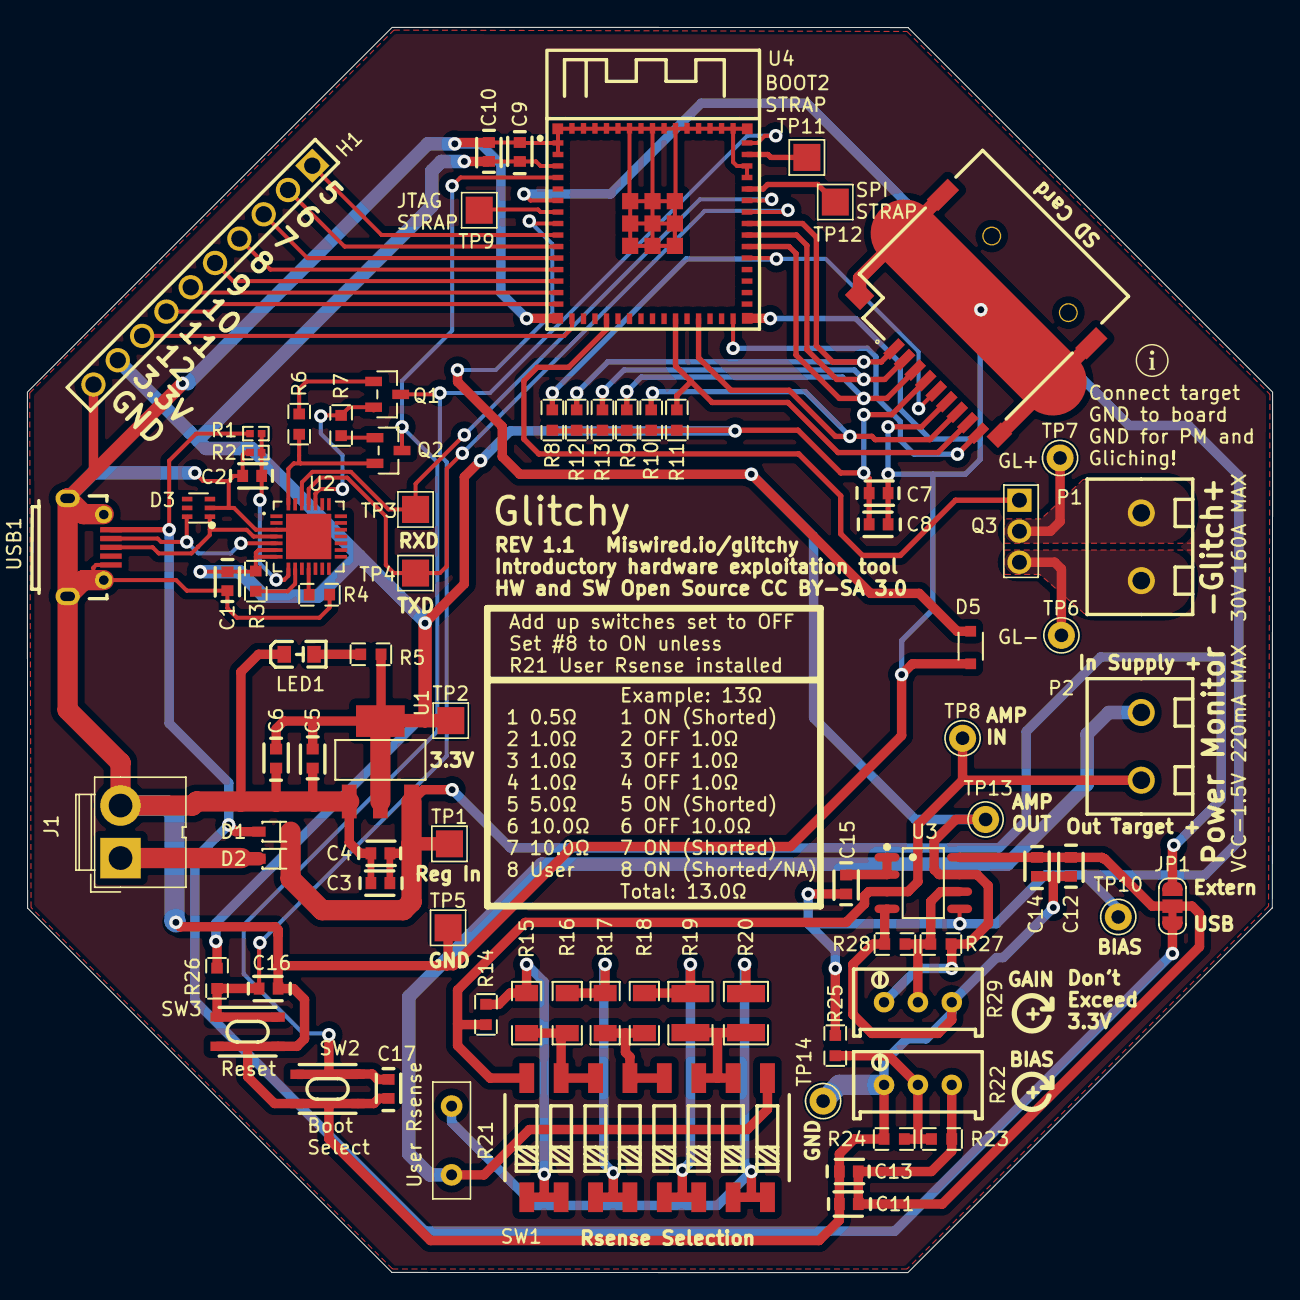
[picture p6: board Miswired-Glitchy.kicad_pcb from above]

Board: 2 copper layers, 92.0 x 92.0 mm, 82 parts (0 on the bottom side), 55 nets.

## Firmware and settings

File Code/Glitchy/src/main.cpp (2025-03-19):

/*
Glitchy
An introduction to hardware exploitation.

This file is licensed under the Creative Commons Attribution-Share Alike 3.0 Unported license.
https://creativecommons.org/licenses/by-sa/3.0/deed.en

Attribution: Miswired
Special thanks goes to Rui Santos and the RandomNerdTutorials site. The work here was inspired by those examples and used with permission.
Please visit https://randomnerdtutorials.com/

    You are free:
        to share – to copy, distribute and transmit the work
        to remix – to adapt the work
    Under the following conditions:
        attribution – You must give appropriate credit, provide a link to the license, and indicate if changes were made. You may do so in any reasonable manner, but not in any way that suggests the licensor endorses you or your use.
        share alike – If you remix, transform, or build upon the material, you must distribute your contributions under the same or compatible license as the original. https://creativecommons.org/share-your-work/licensing-considerations/compatible-licenses
*/

#include <Arduino.h>
#include <WiFi.h>
#include "FS.h"
#include "SD.h"
#include "SPI.h"
#include "pins.h"
#include "web_server.h"
#include "global.h"
#include "glitching.h"
#include "analog_helpers.h"


/* This section is for global compiled options */
#define HOST_ACCESS_POINT   //Uncomment to have Glitchy host it's own wifi network, comment to tell it to connect to an existing network

const char* ssid = "YOUR_SSID_HERE";
const char* password = "YOUR_PASSWORD_HERE";

//Set SSID and Password here if hosting access point
const char* ap_ssid     = "Glitchy";
const char* ap_password = "123456789";

unsigned int g_timer_send_chart_data_ms = 0;
unsigned int g_chart_update_rate_ms = 100;

SPIClass spi_hspi = SPIClass(HSPI);

hw_timer_t *Timer0_Cfg = NULL;

// Initialize SD Card
void initSDCard(){
    uint64_t card_size = 0;
    uint8_t card_type = 0;

    spi_hspi.begin(HSPI_SCLK, HSPI_MISO, HSPI_MOSI, HSPI_SS);
  
    if(!SD.begin(HSPI_SS, spi_hspi, 80000000,"/sd",20)){
      Serial.println("SD Card Init Error");
      return;
    }
    
    //Get the card type
    card_type = SD.cardType();
  
    if(card_type == CARD_NONE){
      Serial.println("No SD Card Detected");
      return;
    }
  
    switch(card_type)
    {
      case CARD_MMC:
        Serial.println("Card Detected is an MMC");
      break;
  
      case CARD_SD:
        Serial.println("Card Detected is an SD");
      break;
  
      case CARD_SDHC:
        Serial.println("Card Detected is an SDHC");
      break;
  
      default:
        Serial.println("Unknown card type");
    }
  
    //Get the size of the SD card
    card_size = SD.cardSize() / (1024 * 1024);
    Serial.printf("SD Card Size: %lluMB\n", card_size);
  }

// Start the wifi module and connect to the configured AP
// Make sure to set up credentials in the wifi_credentials.h file
// If you are connecting to an access point instead of hosting one
void initWiFi() {
    Serial.println("Seting up Wifi");
  
    //Might be good to make unique SSID names automatically, future update.
    /*
    uint8_t mac[8];
    esp_efuse_mac_get_default(mac);
    Serial.print("Mac: ");
    Serial.println("Seting up Wifi");
    */
  
    #ifndef HOST_ACCESS_POINT
  
    Serial.println("SSID Begin");
    WiFi.begin(ssid, password);
    Serial.print("Connecting to WiFi ..");
    while (WiFi.status() != WL_CONNECTED) {
      Serial.print('.');
      delay(1000);
    }
    Serial.println(WiFi.localIP());
  
    WiFi.softAP(ssid, password);
    WiFi.mode(WIFI_STA);
  
    #else
  
    WiFi.softAP(ap_ssid, ap_password);
  
    IPAddress IP = WiFi.softAPIP();
    
    Serial.print("AP IP address: ");
    Serial.println(IP);
    #endif
    
  }

void process_timers()
  {
    if(g_timer_send_chart_data_ms > 0){g_timer_send_chart_data_ms--;}
    
  }

// Inturrupt vector for timer 0
void IRAM_ATTR Timer0_ISR()
{
    process_timers();
}



void setup() {

    Serial.begin(115200);

    pinMode(GLITCH_SUCCESS_PIN, INPUT);
    pinMode(ENTER_KEY_PIN, OUTPUT);
    digitalWrite(ENTER_KEY_PIN, LOW);
    
    initWiFi();
    initSDCard();
    web_server_init();
    initWebSocket();
    init_glitch();
    read_and_send_ADC();
    setup_fast_adc();

    //Inturrupt setup for 1 ms timers

    Timer0_Cfg = timerBegin(0, 240, true);
    
    timerWrite(Timer0_Cfg, 0);
    timerAlarmWrite(Timer0_Cfg, 500, true);
    timerAttachInterrupt(Timer0_Cfg, &Timer0_ISR, true);
    timerAlarmEnable(Timer0_Cfg);


}

void loop() {
  service_webserver();

  if(get_glitching_activate() == true){
    set_glitching_activate(false);

    execute_test_glitch();
    
  }

  if(g_timer_send_chart_data_ms == 0 && get_enable_amp_bias_streaming() == true)
  {
    g_timer_send_chart_data_ms = g_chart_update_rate_ms;
    read_and_send_ADC();
  }

  if(get_send_glitch_params() == true)
  {
    set_send_glitch_params(false);
    send_glitch_params();
  }
}

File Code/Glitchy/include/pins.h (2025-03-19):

#ifndef PINS_H
#define PINS_H

//General system pins
#define POWER_GLITCH_PIN    15
#define AMP_IN_PIN          4
#define BIAS_IN_PIN         2

// Key pins for the power analysis example
#define KEY_1_PIN           5
#define KEY_2_PIN           6
#define KEY_3_PIN           7

// Pins for the glitching example
#define ENTER_KEY_PIN       11
#define GLITCH_SUCCESS_PIN  12

//Set up both SPI's
#define FSPI_MISO   13
#define FSPI_MOSI   POWER_GLITCH_PIN
#define FSPI_SCLK   14
#define FSPI_SS     16

#define HSPI_MISO   47
#define HSPI_MOSI   40
#define HSPI_SCLK   39
#define HSPI_SS     41


#endif

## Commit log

2024-07-29 Initial Commit
    Current state of project, PCB REV1.1 ordered, untested. Code is a collection of small hardware tests. Project not yet complete.
    [Miswired-Glitchy.kicad_pcb, Miswired-Glitchy.kicad_sch]
2024-07-29 Updating some renders and docs
    Accidently had the project circuit breaker docs in here
    [Miswired-Glitchy.kicad_sch]
2024-08-02 Lots of test code added
    The glitchy-tabs-test is the latest featured test code.
    [KeyDiferencesFast.ino, Target_keypad.ino, glitching.ino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]
2024-08-03 Sending values automatically with timer
2024-08-05 Power Analysis good, glitching slow again
    [Target_glitch.ino, Target_keypad.ino, analog.c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]
2024-08-05 latest tests to try and fix the glitch times not working
    [glitching.ino, glitchy-graph-power.ino]
2024-08-05 glitch timing is working manuallygit config user.name miswired!
    [glitching.ino, glitchy-graph-power.ino]
2024-08-06 new project trying spi module, basic test working
2024-08-07 The Gliching and Power both workgit status! Code needs cleaned up
2024-08-08 Lots of changes to try and fix reload bug
    [KeyDiferencesFast.ino, analog.c, analog.h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]
2024-08-12 Fixed CSS parsing warning
    Drop shadow on button apparently had a syntax error.
2024-09-09 Added glitch tuning params
    [glitching.ino]
2025-03-19 Code Ported to PlatformIO
    Major refactor of code. Had to port everything over to PlatformIO and new libraries in order to fix the web loading bug. It's working much better now.
    [analog.c, analog.h, analog_helpers.cpp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]
2026-02-02 Add documentation verification framework and OpenSpec updates
    - Add AGENTS.md with comprehensive verification workflow and examples
    - Add CLAUDE.md with project context and verification system overview
    - Add OpenSpec spec for documentation-verification capability
    - Update tasks.md with Phase 0a (verification) and Phase 0b (code improvements)
    - Add .claude/ directory for agent configuration
    Documentation verification system ensures all technical claims are validated
    against authoritative sources (datasheets, source code, academic papers).
    First 2 tutorials verified (Tutorial-Getting-Started, Tutorial-First-Glitch).
    Identified 3 code improvements for future implementation.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
2026-02-07 Mark Phase 0a documentation verification complete
    All 9 verification tasks complete (0a.1-0a.9):
    - 8 documents verified: 253 total claims
    - 20 issues identified and fixed in wiki
    - Verification files created for all HowTo guides
    Added task 0a.10 to track issue fixes.

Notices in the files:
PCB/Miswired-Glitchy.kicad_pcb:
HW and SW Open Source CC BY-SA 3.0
